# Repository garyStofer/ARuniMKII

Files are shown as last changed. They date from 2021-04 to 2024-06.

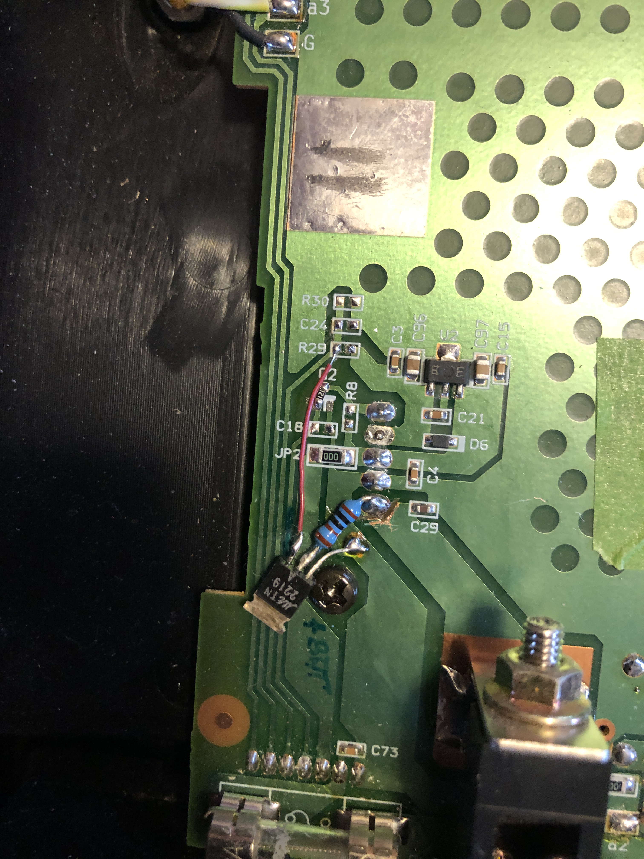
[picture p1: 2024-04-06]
Pictures/IMG_1580.JPG

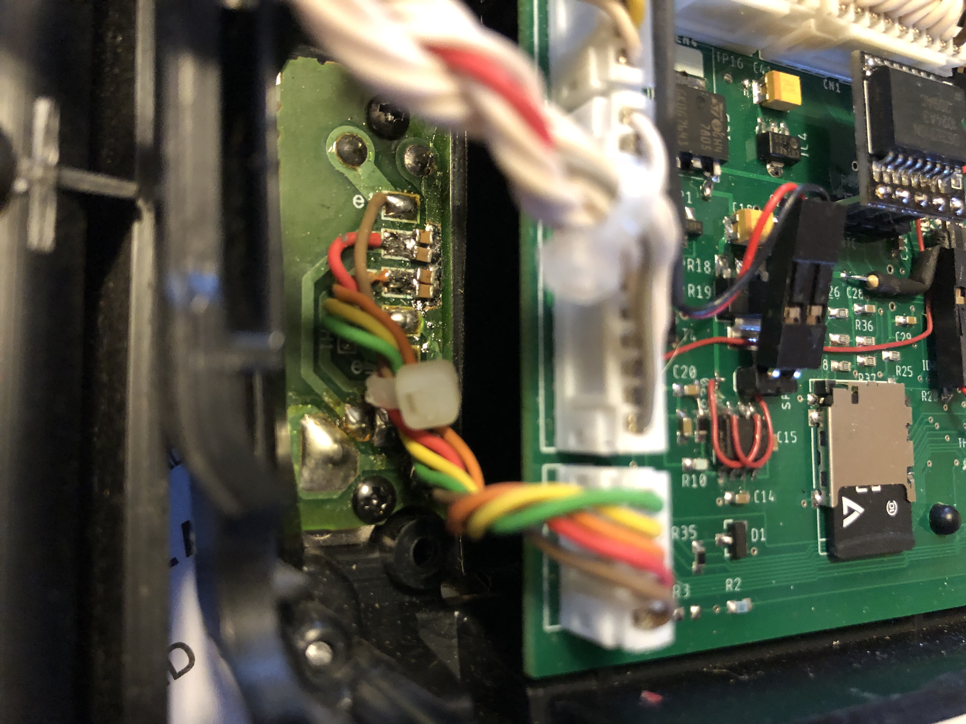
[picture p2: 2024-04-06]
Pictures/IMG_1579.JPG

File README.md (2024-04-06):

# ARuniMKII
PCB  to run ERSKY firmware on old RC transmitters or DIY boxes.

-- Originated from AR9X and ARUni schematic as designed by "flygear" -- on RCgroups

See thread AR9X and ARUni on RC-Groups

Firmware discussions at openrcforums.com under erskyTx (was ersky9x)

Firmware can be found at er9x.com  maintained by Mike Blandford. Use ERSKYTX version  "9XR-PRO" 
Also Pre-Release FW at OpenRCforums : ErskyTX Test Versions by Mike Blandford.

The board is built with an AT-SAM-4 chip with twice the RAM of the original ARUni/AR9x board. See BOM file .
 
The correct chip ID has to be chosen when initially flashing the FW and bootloader to a blank chip with the SAMba tool from Atmel.

firmware src for jr9303 based implementation is at github.com/garyStofer/mbtx

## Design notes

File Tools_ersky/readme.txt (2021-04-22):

These are the latest tools and FW for this board as of  4-2021 -- see er9x.com for more recent versions

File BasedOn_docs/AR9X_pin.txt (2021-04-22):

Corrected AR9X/ARUNI Connector Pin Labels
-----------------------------------------

                             ARUNI Schematic
           AR9X Schematic   (Rev C pin Labels)    MPU Pin     ADC Ch. No.
Sticks
  LV           J3-2         J4-2 (P-ELV_STK)      PA22/AD9         1
  LH           J3-3         J4-3 (P-RUD_STK)      PA19/AD2         0
  RV           J6-2         J6-2 (H-THR_STK)      PC30/AD14        2
  RH           J6-3         J6-3 (H-AIL_STK)      PA18/AD1         3

Pots
  P1           J2-10        J18-2 (F-PO_1)        PA20/AD3         4
  P2           J2-8         J18-4 (F-PO_3)        PC29/AD13        5
  P3           J8-2         J18-3 (F-PO_2)        PB1/AD5          6

Trims
  LVT-U        J3-7         J4-5 (P-ELV_T_DN)     PC28
  LVT-D        J3-9         J4-4 (P-ELV_T_UP)     PA24
  LHT-L        J3-5         J4-7 (P-RUD_T_L)      PA23
  LHT-R        J3-6         J4-6 (P-RUD_T_R)      PB4
  RVT-U        J6-7         J6-5 (H-THR_T_DN)     PA1
  RVT-D        J6-9         J6-4 (H-THR_T_UP)     PC10
  RHT-L        J6-6         J6-7 (H-AIL_T_L)      PA0
  RHT-R        J6-5         J6-6 (H-AIL_T_R)      PC9

NOTE: ARUNI Rev C pin label diagram's:
    - Pots PO_2 and PO_3 got swapped
    - Vertical(ELV/THR) trims' UP/DN got swapped
    - C-RFPWR and C-Board labels got swapped.

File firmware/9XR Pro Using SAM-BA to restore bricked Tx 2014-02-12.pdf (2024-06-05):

DRAFT | 2014-02-12
Using SAM-BA to Restore a “Bricked” Transmitter – version 1 | 1

### 9XR Pro: Using SAM-BA to Restore a “Bricked” Transmitter

The Ersky9x open source firmware used by the Turnigy 9XR Pro computer includes an easy means of communicating between the transmitter and a computer, either via a USB cable or by copying files to a micro-SD card and inserting it into the transmitter.

This capability supports upgrading (flashing) the operating system (firmware) of the transmitter, using a boot loader that comes as part of the firmware. It can also be used to link the transmitter to the Eepskye program, which among other things, enables programming to be performed on the computer and EEPROM files to be backed up to the computer.

What the firmware cannot do is to reload itself if the transmitter becomes “bricked”, i.e., totally unresponsive. In that case, the firmware must be erased from the transmitter and reinstalled. Re-installing requires the use of SAM-BA, a program provided by Atmel, the maker of the ARM microprocessor used by the 9XR Pro transmitter.

### Requirements

As detailed below, SAM-BA is available for download from the Atmel Corporation.

SAM-BA can run under Windows XP, 7 or 8. There is no Macintosh version but it may be possible to run SAM-BA in a Boot Camp Windows partition.

To connect the transmitter to the computer, a USB cable with a Mini-B connector (as used by many older mobile phones) is required. The USB port is under a rubber flap on the bottom of the transmitter. Press the mini USB plug firmly into the socket to ensure that it connects.

Note that some mini-USB cables only support charging. If you encounter a problem connecting, try another cable. Also try a different USB port on the computer. Note that USB 3 ports may not work with any but the newest versions of SAM-BA.

### Installing SAM-BA

- Go to the Atmel Corporation site and download the SAM-BA Version 2.12 file. You will have to register temporarily with Atmel to do so.
- Unzip the file onto your desktop (i.e., right click on the .zip file and select ‘expand file’).
- Open the sam-ba_2.12 file to open the wizard; follow the prompts. The wizard will ask if you wish to install the files in a folder called “Atmel” in the Program Files directory of your hard disk. Answer ‘Yes’ and continue with the prompts.
- The usual path is something like C:\ProgramFiles\Atmel\sam-ba_2.12. Write down or remember where to find this folder. Install a shortcut on the desktop when asked to do so by the wizard. Continue until the wizard is finished.
- Download the file at91sam3s8-9xr.zip from the following location: ‪http://openrcforums.com/forum/viewtopic.php?f=118&t=4553&start=60#p65474
- Unzip the file to a convenient location such as the desktop. It contains a folder called at91sam3s8-9xr.tcl (within which are three applet files and a couple of .tcl files) plus a file called boards.tcl.
- Within the folder where SAM-BA is installed is a folder called tcl_lib. Drag the folder you have just extracted into it. Answer ‘Yes’ to any request to overwrite existing files. The result should be that within the tcl_lib folder (1) the boards.tcl file is replaced (the date may be older than the one it replaces), (2) a new folder called at91sam3s4-9x is created, (3) a new folder called common is created.

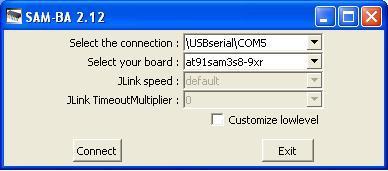
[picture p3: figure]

Using SAM-BA to Restore a “Bricked” Transmitter – version 1 | 2

To check the installation, connect the transmitter (turned OFF) to a USB port on your computer. When you turn the radio on you‪should‪see‪‘USB’‪on‪the‪screen.‪Start the SAM-BA program from the shortcut on the desktop and you will see a dialogue box. From the ‘Select your board’ menu choose at91sam3s8-9xr. If the result looks like the following image (except‪possibly‪for‪a‪different‪COM‪number)‪and‪the‪‘Connect’‪button‪is‪not‪greyed‪ out, you have been successful.

Write down the connection path accurately (including all capitalization) for later reference.

(Note that if you are using Windows XP and the dialogue box shows blanks for connection and‪board,‪you‪may‪need‪to‪find‪and‪install‪a‪driver‪for‪“GPS‪Camera‪Detect.”)

You can now quit SAM-BA.‪Use‪the‪Windows‪‘Safely Remove‪Hardware‪and‪Eject‪Media’ function, then turn off and disconnect the transmitter.

Note that the number following COM is that of the USB port into which you plugged your cable. Try to use this same port whenever you connect to your transmitter. If you do use another port, or forget the number of the one you used, press the Start button (Windows 7) and go to Devices‪and‪Printers.‪There‪under‪‘Unspecified’‪you‪should‪see‪something‪like‪ ‘GPS Camera Detect (COM5)’. Edit the COM number in the SAM-BA connection to match.

### Using SAM-BA to Recover a Bricked Transmitter

A transmitter‪that‪is‪unresponsive‪(‘bricked’) because of a firmware issue requires that the ARM processor chip be restored to factory defaults and that fresh firmware be flashed to it using the SAM-BA program.

New releases of firmware are available at: http://ersky9x.googlecode.com/svn/trunk/ersky9x_rom.bin

Step 1: Erasing the Chip
- While turning ON the transmitter, use a paperclip to press and hold the small round Erase Button. It is in a hole beside the USB connector, under the rubber flap on the bottom of the transmitter. The Atmel ARM chip will be reset to factory defaults.

Caution: Pressing the Erase Button completely wipes the firmware off the chip; it does NOT restore the transmitter to original firmware.

Step 2: Updating Firmware
- Download the firmware file to the desktop or a folder where you can find it later. Unzip the file if necessary. The firmware will be in a file such as ersky9xr_rom.bin.
- Connect the transmitter to the same USB port on your computer that was used to install SAM-BA. Turn the transmitter ON. The radio should display ‘USB’ on the screen and the computer make the ‘successful connection’ sound.
- Start SAM-BA from the shortcut on the desktop. You will see the SAM-BA dialogue box.

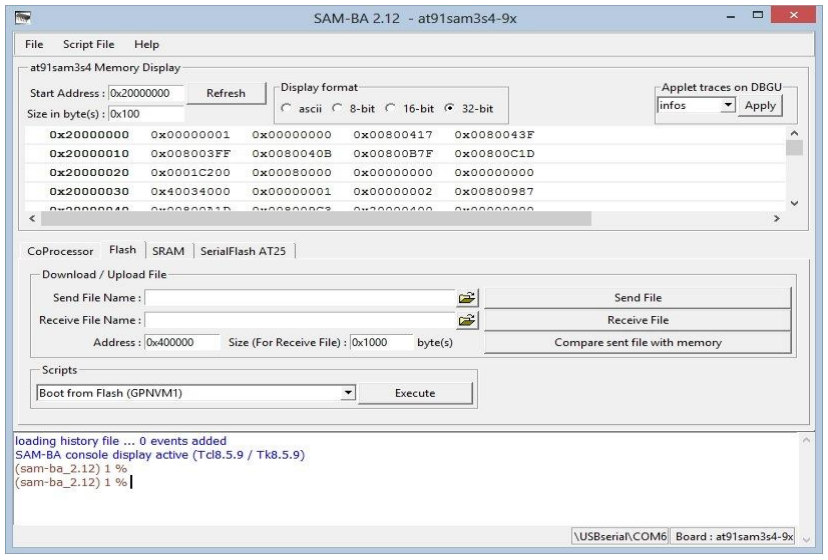
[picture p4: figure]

Using SAM-BA to Restore a “Bricked” Transmitter – version 1 | 3
- Click ‘Connect’. Windows may take up to a minute to connect. You should see:
- Use the browse button next to the "Send File Name" Box to locate and select the new firmware file on your computer.
- Click the "Send File" button. You should see the file upload in the dialog box at the bottom – the process should only take a couple of seconds to complete. The new firmware is now installed (including the boot loader for future firmware updates).
- In‪Scripts‪window‪near‪the‪bottom‪of‪the‪page‪select‪“Boot‪from‪Flash‪(GPNVM1)”
- Click the Execute button.
- After the programming is finished, you will see an option to ‘lock’ the firmware. DO NOT LOCK THE FIRMWARE! Select the "No" button. (If you do accidentally press "Yes" and lock the firmware, it will be necessary to erase the chip and reload the firmware. Otherwise it will be impossible to do any updates.)
- Quit SAM-BA. Then use ‘Safely‪Remove‪Hardware‪and‪Eject‪Media’,‪turn the transmitter OFF and disconnect the USB cable.
- Turn on the transmitter and check its operation with the new firmware.

### NOTES

- SAM-BA only works once each time it is started. After each use you must quit SAM-BA, turn off the radio, and disconnect the transmitter from the USB port. Only then can you reconnect and upload or download a file.
- It is important to connect the transmitter to your computer and turn it on before starting SAM-BA, otherwise the program will not work.
- Be sure to quit the SAM-BA program before shutting down the transmitter.
- To enter boot loader mode, turn on the transmitter while holding the two horizontal trim levers towards the centre; the transmitter is then ready to flash firmware. As well, in this mode, the USB cable can be used to connect with the computer. For details, see
9XR Pro: Communicating with a Computer.

Using SAM-BA to Restore a “Bricked” Transmitter – version 1 | 4

### Further Information

For additional information to help you understand and make best use of your Turnigy 9XR Pro, see the other manuals in this series and/or go to one of the forums dedicated to this transmitter and the open source firmware it uses.

9XR Pro Manuals
The following manuals are designed to help you get the most out of your Turnigy 9XR Pro. They are available at: http://openrcforums.com/forum/viewforum.php?f=7
1. 9XR Pro: Introduction to the Hardware
2. 9XR Pro: First Steps with Ersky9x
3. 9XR Pro: Ersky9x Explained
4. 9XR Pro: Communicating with a Computer
5. 9XR Pro: Using Voice with Ersky9x
6. 9XR Pro: Using the Eepskye Program
7. 9XR Pro: Glossary of Terms

Internet Forums
Help is always just a few clicks away on the internet forums where experienced Ersky9x users volunteer their knowledge and experience. Many of these people have been developing the firmware for years without remuneration; all they ask is donations to fund further development.

Open RC Forums: http://openrcforums.com/forum/index.php

Ersky9x index page: http://openrcforums.com/forum/

9XR index page: http://openrcforums.com/forum/viewforum.php?f=70

### NOTICE

Ersky9x and Eepskye are free open source software, independently developed. This manual is provided to help you understand and use them specifically for the Turnigy 9XR Pro transmitter, though much of the information also applies to the Sky replacement boards produced as an upgrade for the 9x transmitter.

You can redistribute the software and/or modify it under the terms of the GNU General Public License version 2 as published by the Free Software Foundation. You can also freely quote from, redistribute and/or modify this manual; in doing so please acknowledge the source and any changes.

The program and the manuals are distributed in the hope that they will be useful, but WITHOUT ANY WARRANTY; without even the implied warranty of MERCHANTABILITY or FITNESS FOR A PARTICULAR PURPOSE. See the GNU General Public License for more details. In using them, you agree that you accept all responsibility.

For more information go to: http://openrcforums.com/forum/viewforum.php?f=7

9XR Pro Using SAM-BA to restore bricked Tx 2014-02-12

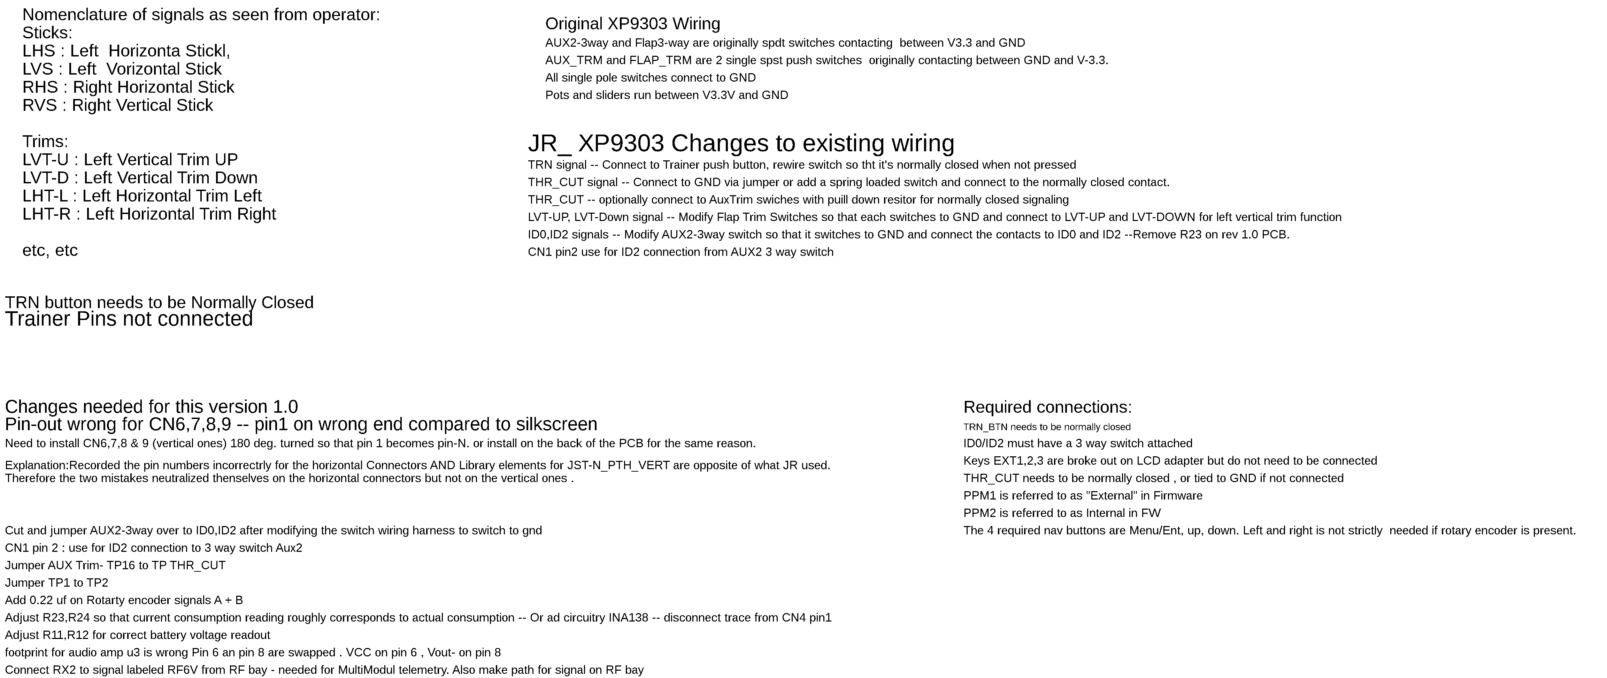
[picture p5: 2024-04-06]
Pictures/page2.png

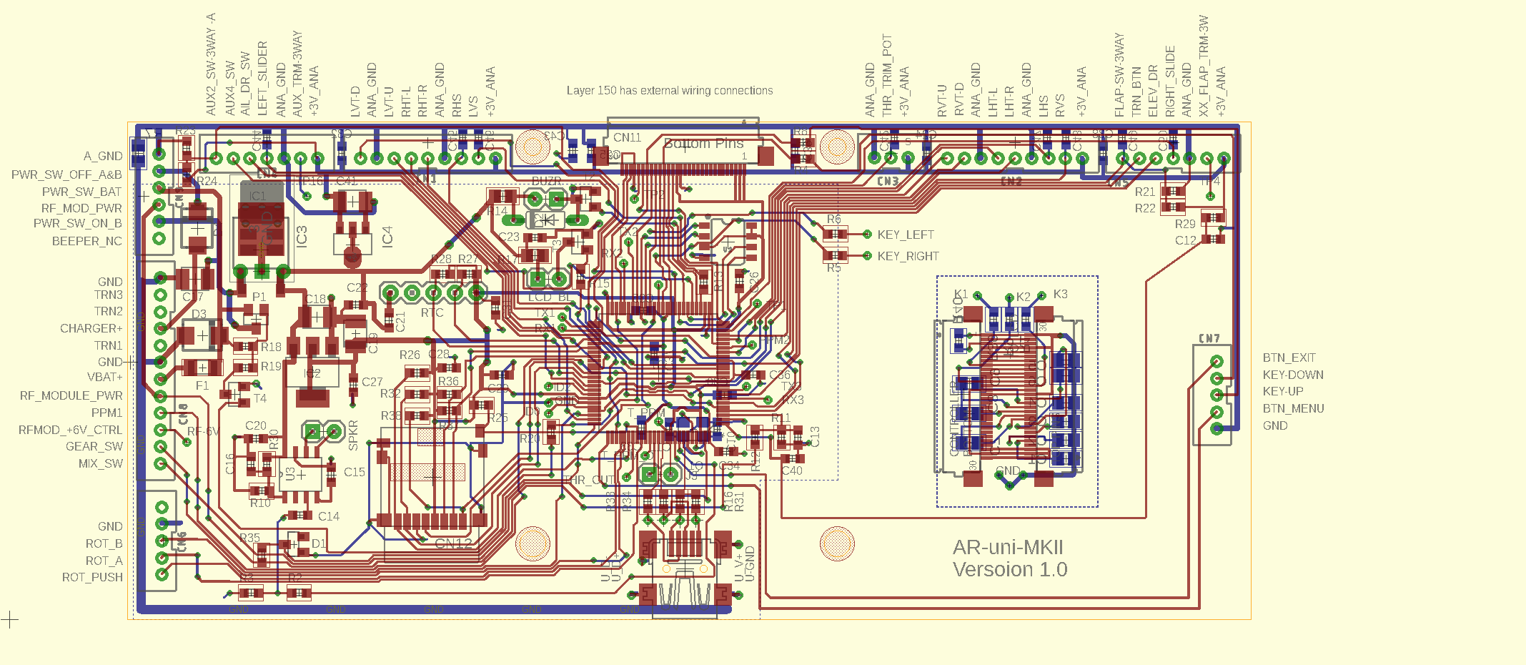
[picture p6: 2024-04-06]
Pictures/pcb_front .png

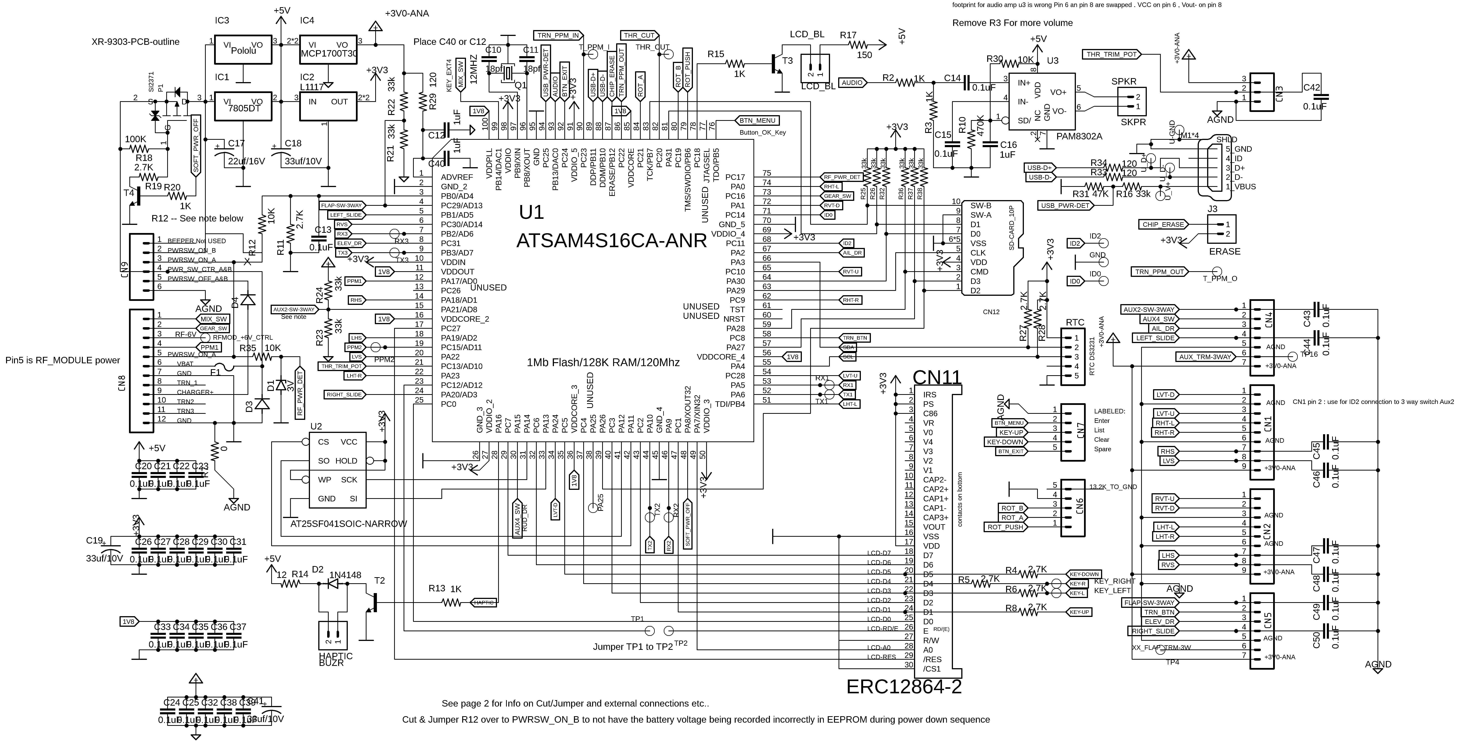
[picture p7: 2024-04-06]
Pictures/page1.png

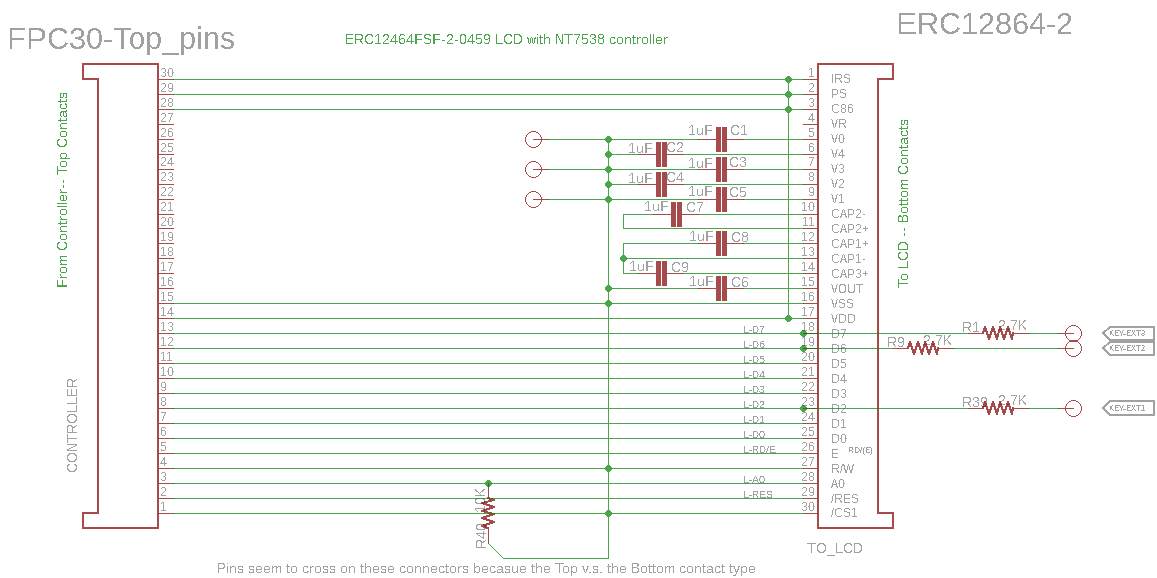
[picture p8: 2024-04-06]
Pictures/Page3_sch.png

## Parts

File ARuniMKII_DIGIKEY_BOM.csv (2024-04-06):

Manufacturer Part Number | Manufacturer | Digi-Key Part Number | Customer Reference | Reference Designator | Packaging | Part Status | Quantity | Unit Price | Extended Price | Quantity Available | Mfg Std Lead Time | Description | RoHS Status | Lead Free Status | REACH Status
ATSAM4S16CA-ANR | Microchip Technology | 1611-ATSAM4S16CA-ANRCT-ND |  |  | Cut Tape (CT) | Active | 2 | 3.03000 | $6.06 | 391 | 27 Weeks | IC MCU 32BIT 1MB FLASH 100LQFP | ROHS3 Compliant | Lead free | REACH Unaffected
DM3D-SF | Hirose Electric Co Ltd | HR1941CT-ND |  |  | Cut Tape (CT) | Active | 2 | 1.65000 | $3.30 | 0 | 12 Weeks | CONN MICRO SD CARD PUSH-PULL | RoHS Compliant | Lead free | Not Available
SI2371EDS-T1-GE3 | Vishay Siliconix | SI2371EDS-T1-GE3CT-ND |  |  | Cut Tape (CT) | Active | 10 | 0.31600 | $3.16 | 57370 | 19 Weeks | MOSFET P-CH 30V 4.8A SOT-23 | ROHS3 Compliant | Lead free | Not Available
SF-1206SP175L-2-A9 | Bourns Inc. | 118-SF-1206SP175L-2-A9CT-ND |  |  | Cut Tape (CT) | Active | 5 | 0.20200 | $1.01 | 8499 | 20 Weeks | FUSE BOARD MNT 1.75A 63VDC 1206 | ROHS3 Compliant | Lead free | REACH Unaffected
PAM8302AADCR | Diodes Incorporated | PAM8302AADCRDICT-ND |  |  | Cut Tape (CT) | Active | 2 | 0.65000 | $1.30 | 4154 | 36 Weeks | IC AMP CLASS D MONO 2.5W 8SOP | ROHS3 Compliant | Lead free | REACH Unaffected
TPSB336K010R0500 | AVX Corporation | 478-9074-1-ND |  |  | Cut Tape (CT) | Active | 10 | 0.31700 | $3.17 | 505 | 33 Weeks | CAP TANT 33UF 10% 10V 1411 | ROHS3 Compliant | Lead free | REACH Unaffected
TPSB226K016R0600 | AVX Corporation | 478-1758-1-ND |  |  | Cut Tape (CT) | Active | 2 | 0.50000 | $1.00 | 0 | 33 Weeks | CAP TANT 22UF 10% 16V 1411 | ROHS3 Compliant | Lead free | REACH Unaffected
LDL1117S33R | STMicroelectronics | 497-17239-1-ND |  |  | Cut Tape (CT) | Active | 2 | 0.38000 | $0.76 | 0 | 26 Weeks | IC REG LINEAR 3.3V 1.2A SOT223 | ROHS3 Compliant | Not Available | REACH Unaffected
BZX84B3V0-7-F | Diodes Incorporated | BZX84B3V0-FDICT-ND |  |  | Cut Tape (CT) | Active | 2 | 0.20000 | $0.40 | 19778 | 34 Weeks | DIODE ZENER 3V 300MW SOT23 | ROHS3 Compliant | Lead free | REACH Unaffected
MCP1700T-3002E/MB | Microchip Technology | MCP1700T-3002E/MBCT-ND |  |  | Cut Tape (CT) | Active | 2 | 0.39000 | $0.78 | 0 | 10 Weeks | IC REG LINEAR 3V 250MA SOT89-3 | ROHS3 Compliant | Lead free | REACH Unaffected
SFV30R-2STBE1HLF | Amphenol ICC (FCI) | 609-5394-1-ND |  |  | Cut Tape (CT) | Active | 1 | 0.64000 | $0.64 | 10225 | 14 Weeks | CONN FFC TOP 30POS 0.50MM R/A | RoHS Compliant | Lead free | REACH Unaffected
0151660319 | Molex | 0151660319-ND |  |  | Bag | Active | 2 | 1.97000 | $3.94 | 438 | 10 Weeks | CABLE FFC 30POS 0.50MM 3" | ROHS3 Compliant | Lead free | Not Available
68713014522 | Würth Elektronik | 732-3518-1-ND |  |  | Cut Tape (CT) | Active | 4 | 1.62000 | $6.48 | 2728 | 11 Weeks | CONN FPC BOTTOM 30POS 0.50MM R/A | ROHS3 Compliant | Lead free | REACH Unaffected
68713014022 | Würth Elektronik | 732-3517-1-ND | top pins |  | Cut Tape (CT) | Active | 2 | 1.67000 | $3.34 | 1897 | 11 Weeks | CONN FPC TOP 30POS 0.50MM R/A | ROHS3 Compliant | Lead free | REACH Unaffected
RMCF0603FT2K70 | Stackpole Electronics Inc | RMCF0603FT2K70CT-ND |  |  | Cut Tape (CT) | Active | 100 | 0.00680 | $0.68 | 0 | 21 Weeks | RES 2.7K OHM 1% 1/10W 0603 | ROHS3 Compliant | Lead free | REACH Unaffected
WR06X3302FTL | Walsin Technology Corporation | 1292-WR06X3302FTLCT-ND |  |  | Cut Tape (CT) | Active | 100 | 0.00560 | $0.56 | 4302 | 25 Weeks | RES 33K OHM 1% 1/10W 0603 | ROHS3 Compliant | Not Available | REACH Unaffected
CR0603-JW-104ELF | Bourns Inc. | CR0603-JW-104ELFCT-ND |  |  | Cut Tape (CT) | Active | 100 | 0.00530 | $0.53 | 50214 | 14 Weeks | RES SMD 100K OHM 5% 1/10W 0603 | ROHS3 Compliant | Lead free | REACH Unaffected
690-005-299-043 | EDAC Inc. | 151-1206-1-ND |  |  | Cut Tape (CT) | Active | 2 | 0.54000 | $1.08 | 71096 | 17 Weeks | CONN RCPT USB2.0 MINI B SMD R/A | ROHS3 Compliant | Lead free | REACH Unaffected
B12B-PH-K-S(LF)(SN) | JST Sales America Inc. | 455-1714-ND |  |  | Bulk | Active | 2 | 0.53000 | $1.06 | 3158 | 24 Weeks | CONN HEADER VERT 12POS 2MM | ROHS3 Compliant | Lead free | Not Available
B7B-PH-K-S(LF)(SN) | JST Sales America Inc. | 455-1709-ND |  |  | Bulk | Active | 4 | 0.39000 | $1.56 | 359 | 24 Weeks | CONN HEADER VERT 7POS 2MM | ROHS3 Compliant | Lead free | Not Available
B6B-PH-K-S(LF)(SN) | JST Sales America Inc. | 455-1708-ND |  |  | Bulk | Active | 4 | 0.33000 | $1.32 | 11870 | 24 Weeks | CONN HEADER VERT 6POS 2MM | ROHS3 Compliant | Lead free | REACH Unaffected
SWR201-NRTN-S05-SA-WH | Sullins Connector Solutions | S9450-ND |  |  | Bulk | Active | 4 | 0.22000 | $0.88 | 1435 | 4 Weeks | CONN HEADER VERT 5POS 2MM | ROHS3 Compliant | Lead free | REACH Unaffected
SWR201-NRTN-S03-SA-WH | Sullins Connector Solutions | S9456-ND |  |  | Bulk | Active | 2 | 0.17000 | $0.34 | 2064 | 5 Weeks | CONN HEADER VERT 3POS 2MM | ROHS3 Compliant | Lead free | REACH Unaffected
440054-9 | TE Connectivity AMP Connectors | A100041-ND |  |  | Bulk | Active | 4 | 0.59000 | $2.36 | 0 | 25 Weeks | CONN HEADER VERT 9POS 2MM | RoHS Compliant | Lead free | Not Available
LFXTAL083388RL3K | IQD Frequency Products | 1923-LFXTAL083388RL3KCT-ND |  |  | Cut Tape (CT) | Active | 2 | 0.66000 | $1.32 | 2433 | 19 Weeks | CRYSTAL 12.0000MHZ 12PF SMD | ROHS3 Compliant | Not Available | Not Available
CL10C120JB8NNNC | Samsung Electro-Mechanics | 1276-1254-1-ND |  |  | Cut Tape (CT) | Active | 50 | 0.01720 | $0.86 | 136019 | 28 Weeks | CAP CER 12PF 50V C0G/NP0 0603 | ROHS3 Compliant | Lead free | REACH Unaffected
MMBT3904-7-F | Diodes Incorporated | MMBT3904-FDICT-ND |  |  | Cut Tape (CT) | Active | 25 | 0.08280 | $2.07 | 636895 | 20 Weeks | TRANS NPN 40V 0.2A SMD SOT23-3 | ROHS3 Compliant | Lead free | REACH Unaffected
AT25SF041B-SHD-B | Adesto Technologies | 1265-AT25SF041B-SHD-B-ND |  |  | Tube | Active | 2 | 0.36000 | $0.72 | 8168 | 12 Weeks | IC FLASH 4MBIT SPI/QUAD 8SOIC | ROHS3 Compliant | Not Available | REACH Unaffected

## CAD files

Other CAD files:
BasedOn_docs/ARUni_Wiring_v14.dwg

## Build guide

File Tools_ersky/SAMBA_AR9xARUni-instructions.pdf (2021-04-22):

AR9x, ARUni Firmware flashing via SAM-BA tool

*CHIP_ERASE can be done short “CHIP_ERASE” pin to 3.3V and power up the board.

### 1. Ready board as powered off 2. Install SAM-BA program on your PC

(https://www.rcgroups.com/forums/showatt.php?attachmentid=8531632&d=1450682596)

### 3. Connect micro USB cable between PC and the board (Powered off) 4. Power up the board 5. Driver for “Bossa Program Port” is being installed

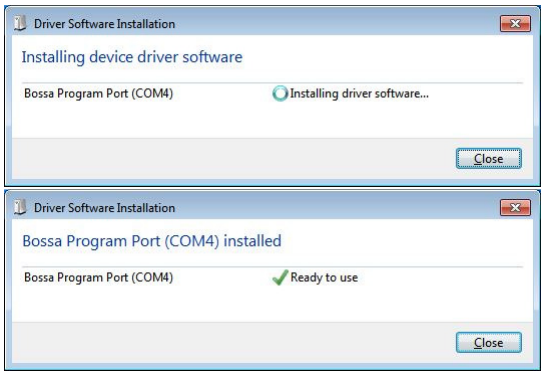
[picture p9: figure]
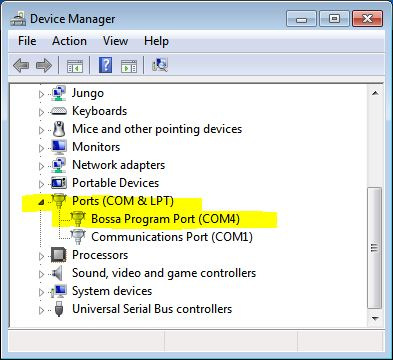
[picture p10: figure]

6. Confirm “Bossa Program Port” is installed on the Windows device manager.

### 7. Excute SAM-BA from PC

### 8. Select the connection & board type and Click “Connect”

a. Check your board type first refer (https://static.rcgroups.net/forums/attachments/3/1/9/8/5/0/a8977372-192-a8828688-168-AR9x_lot_1.PNG)
b. If your board type is “3S8” select your board type as “at91sam3s8-ek”

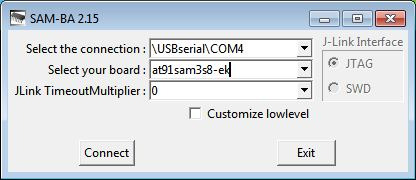
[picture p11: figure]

c. If your board type is “3SD8” select your board type as “at91sam3sd8-ek”

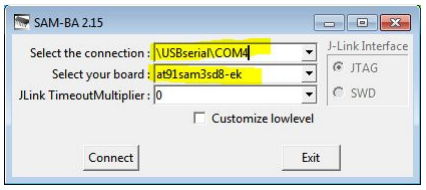
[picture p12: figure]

### 9. Choose the firmware you want to send to the board

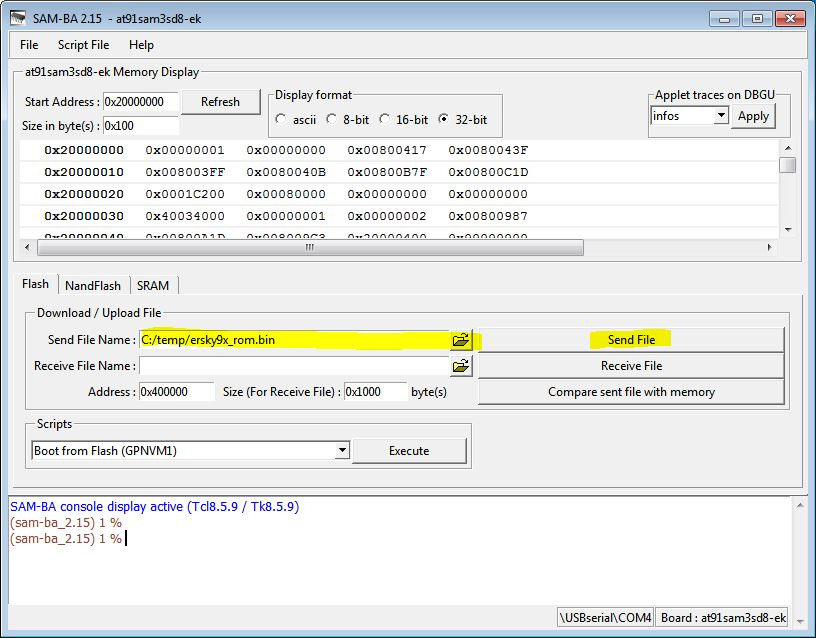
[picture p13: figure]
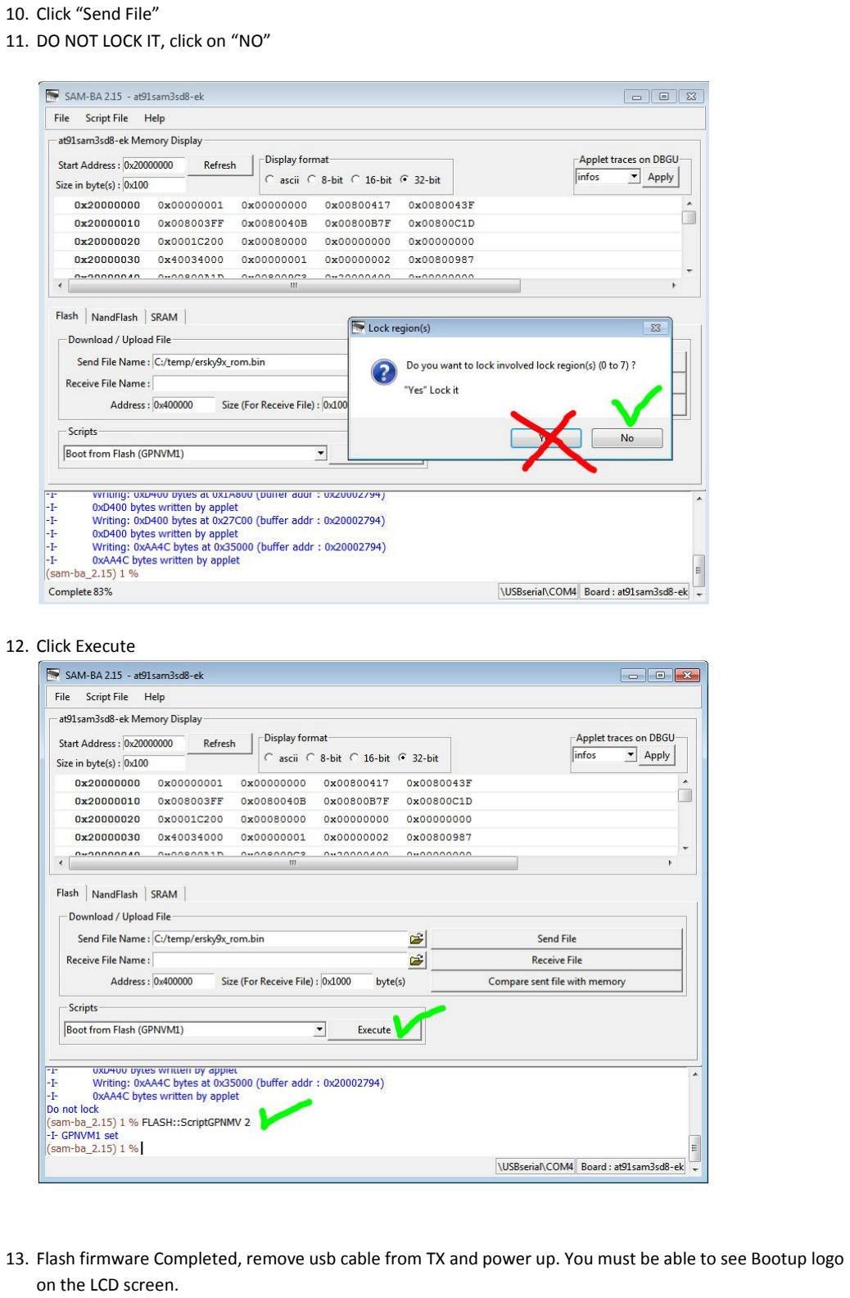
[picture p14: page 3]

### 10. Click “Send File” 11. DO NOT LOCK IT, click on “NO”

### 12. Click Execute

13. Flash firmware Completed, remove usb cable from TX and power up. You must be able to see Bootup logo on the LCD screen.

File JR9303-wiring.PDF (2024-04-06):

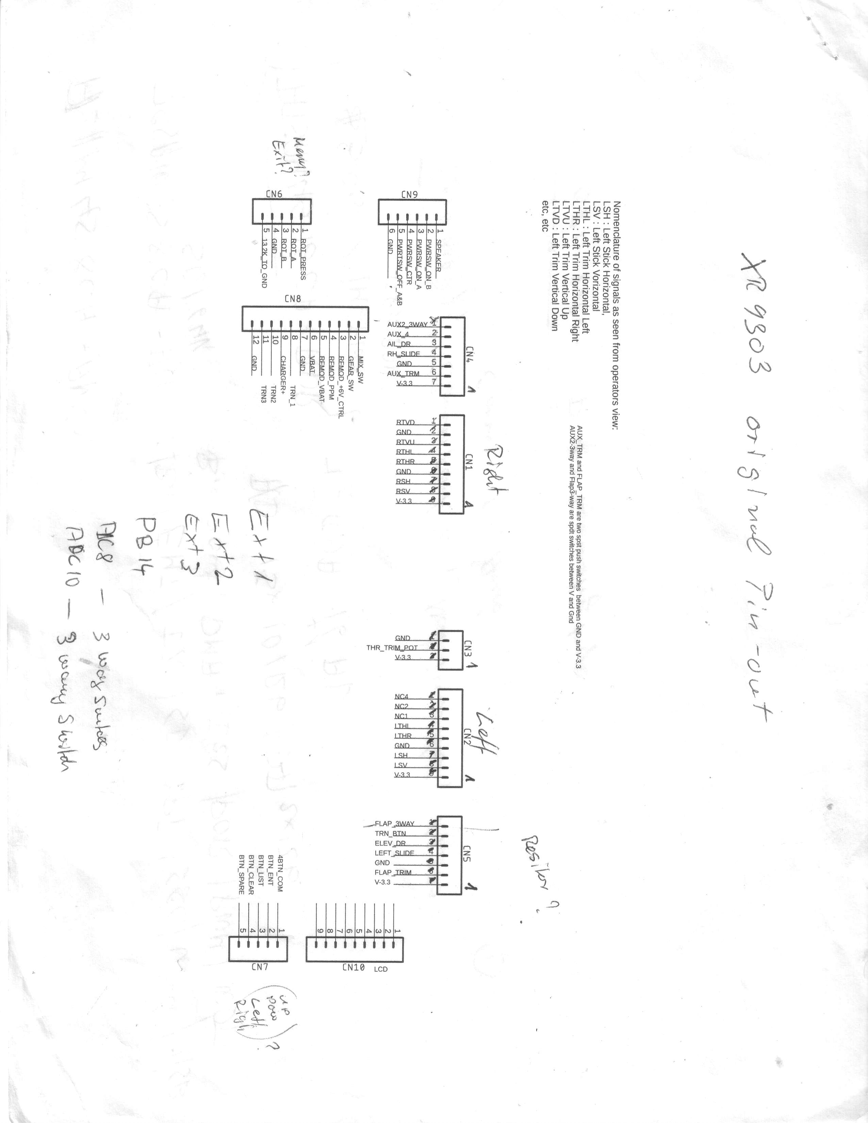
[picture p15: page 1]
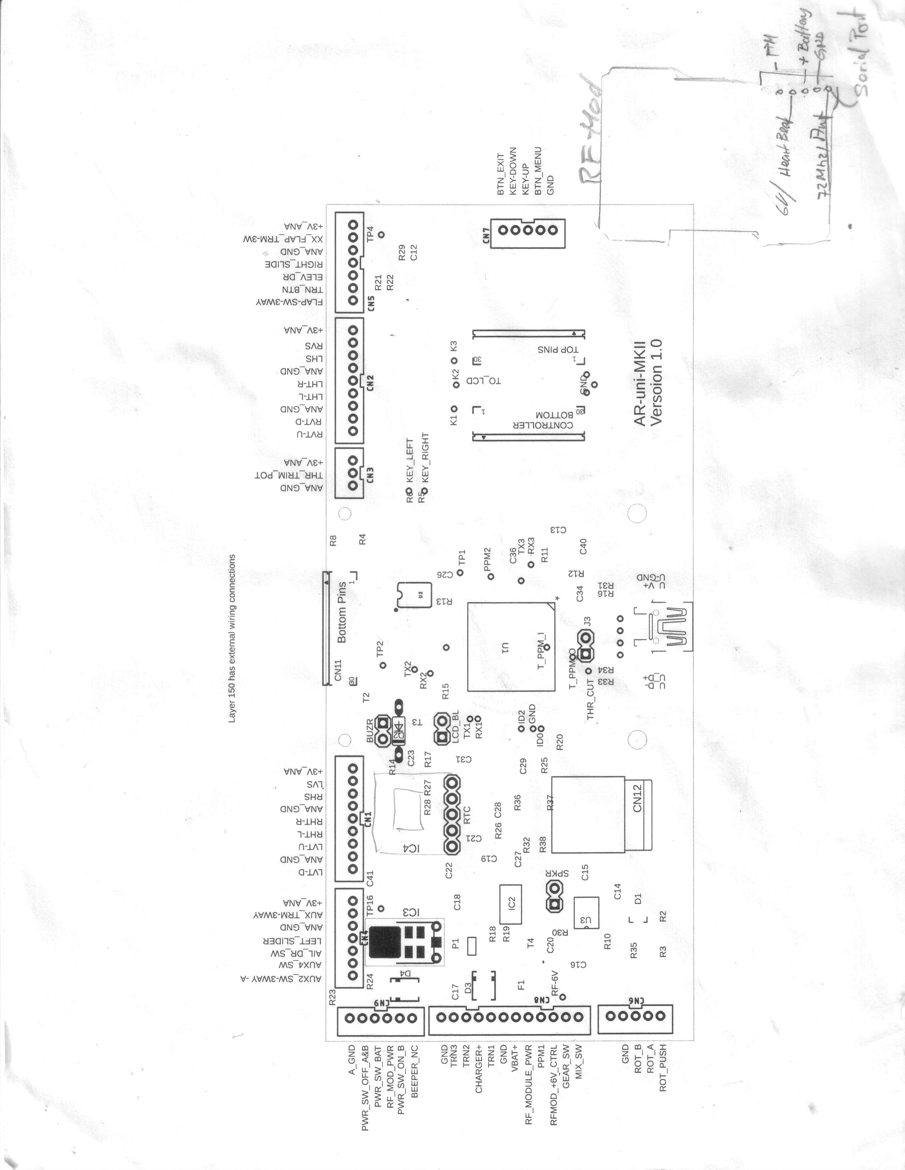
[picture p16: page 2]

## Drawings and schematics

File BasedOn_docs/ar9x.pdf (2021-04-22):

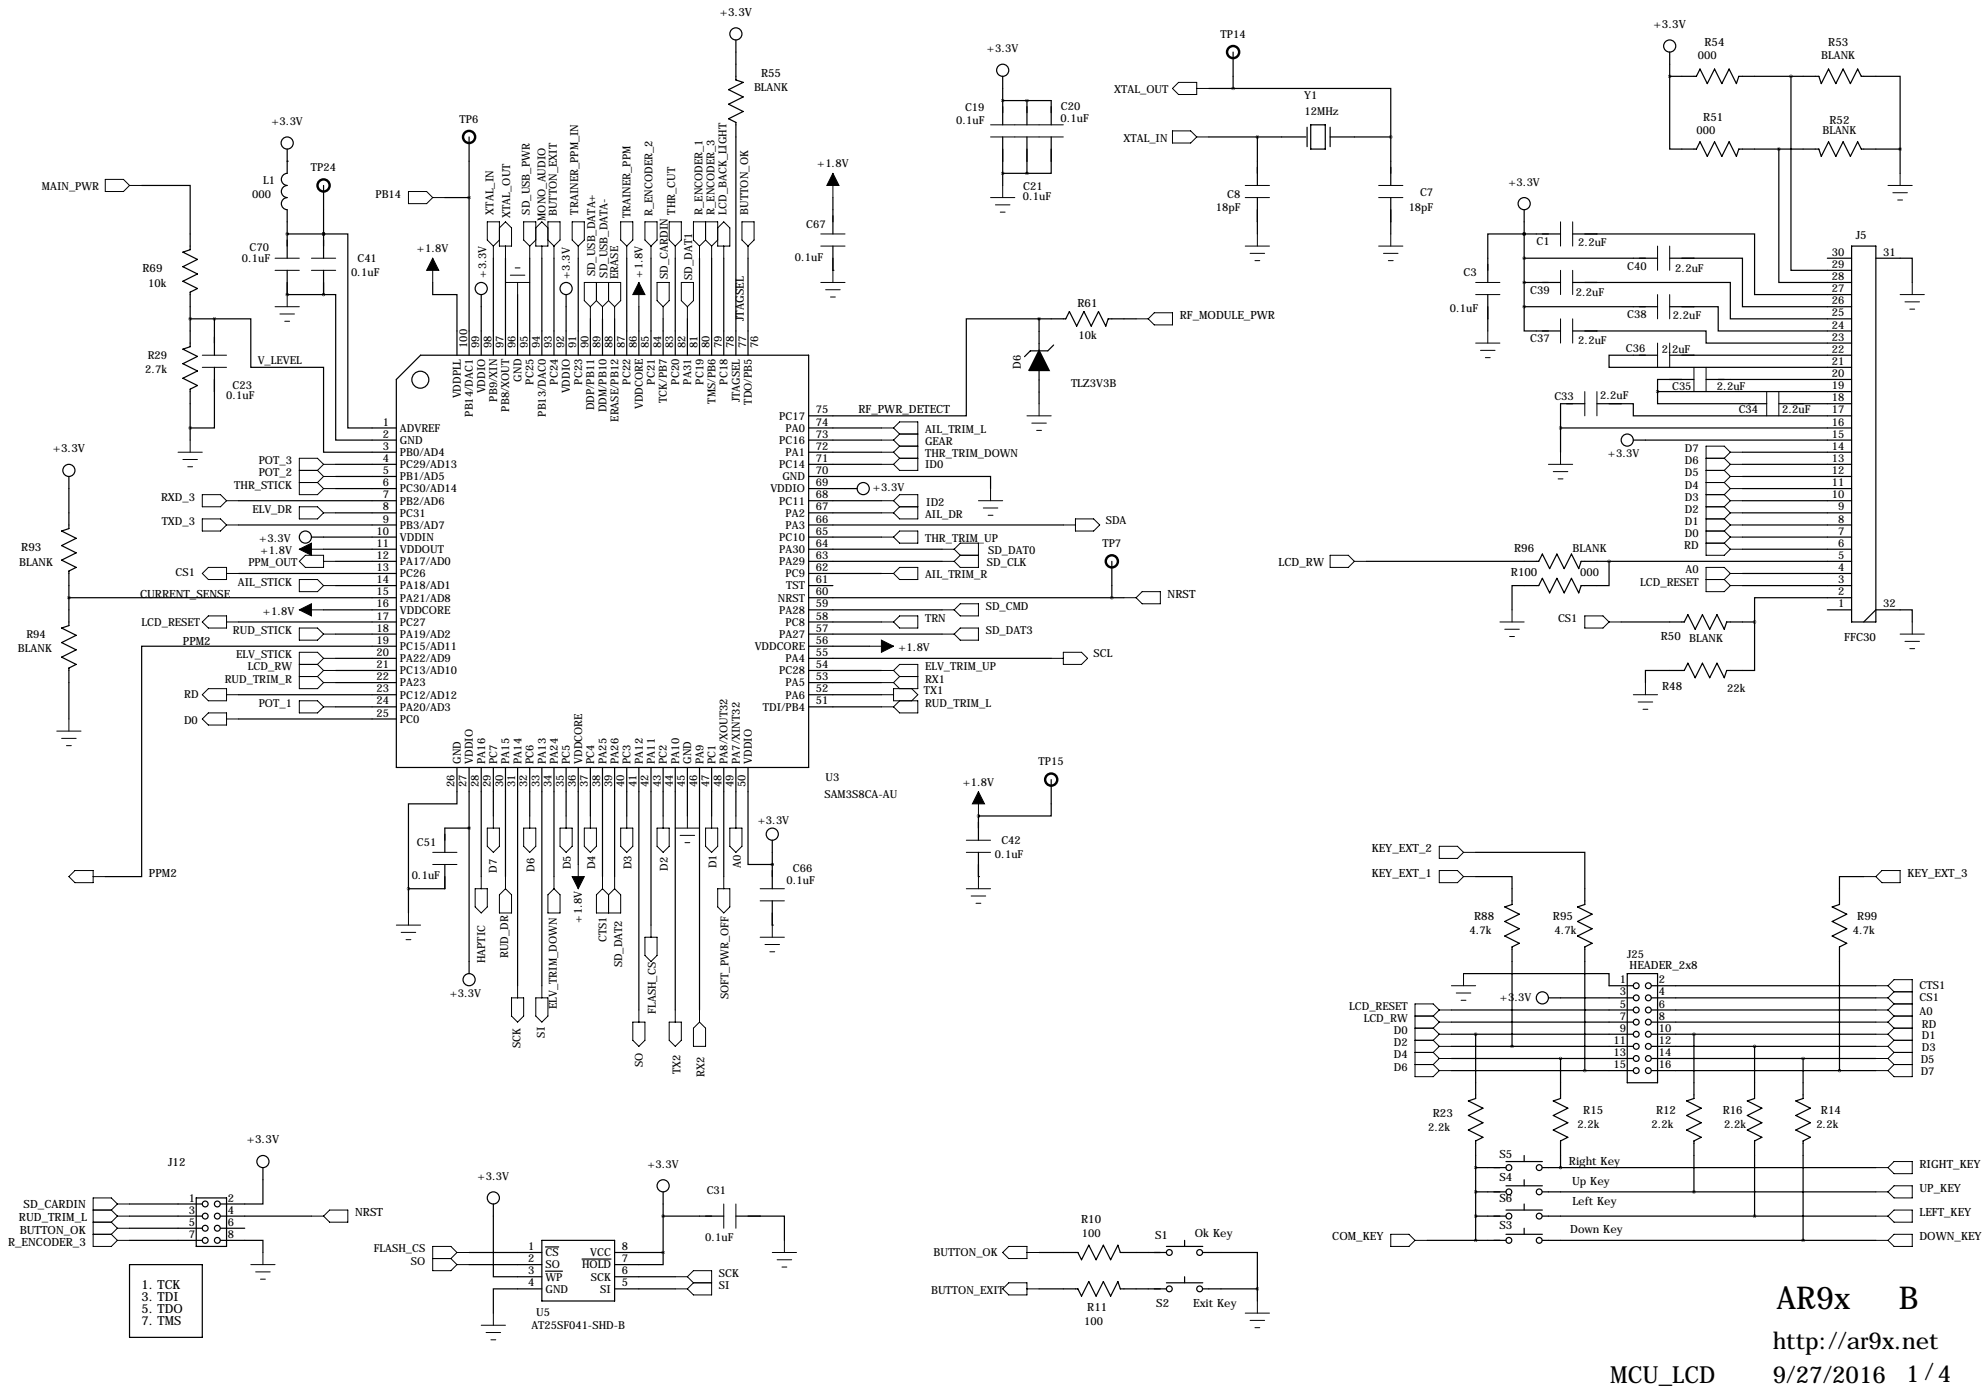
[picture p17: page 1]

76 TDO/PB5 77 JTAGSEL 78 PC18 79 TMS/PB6 80 PC19 81 PA31 82 PC20 83 TCK/PB7 84 PC21 85 VDDCORE 86 PC22 87 ERASE/PB12 88 DDM/PB10 89 DDP/PB11 90 PC23 91 VDDIO 92 PC24 93 PB13/DAC0 94 PC25 95 GND 96 PB8/XOUT 97 PB9/XIN 98 VDDIO 99 PB14/DAC1 100 VDDPLL

# PWR Slide SW

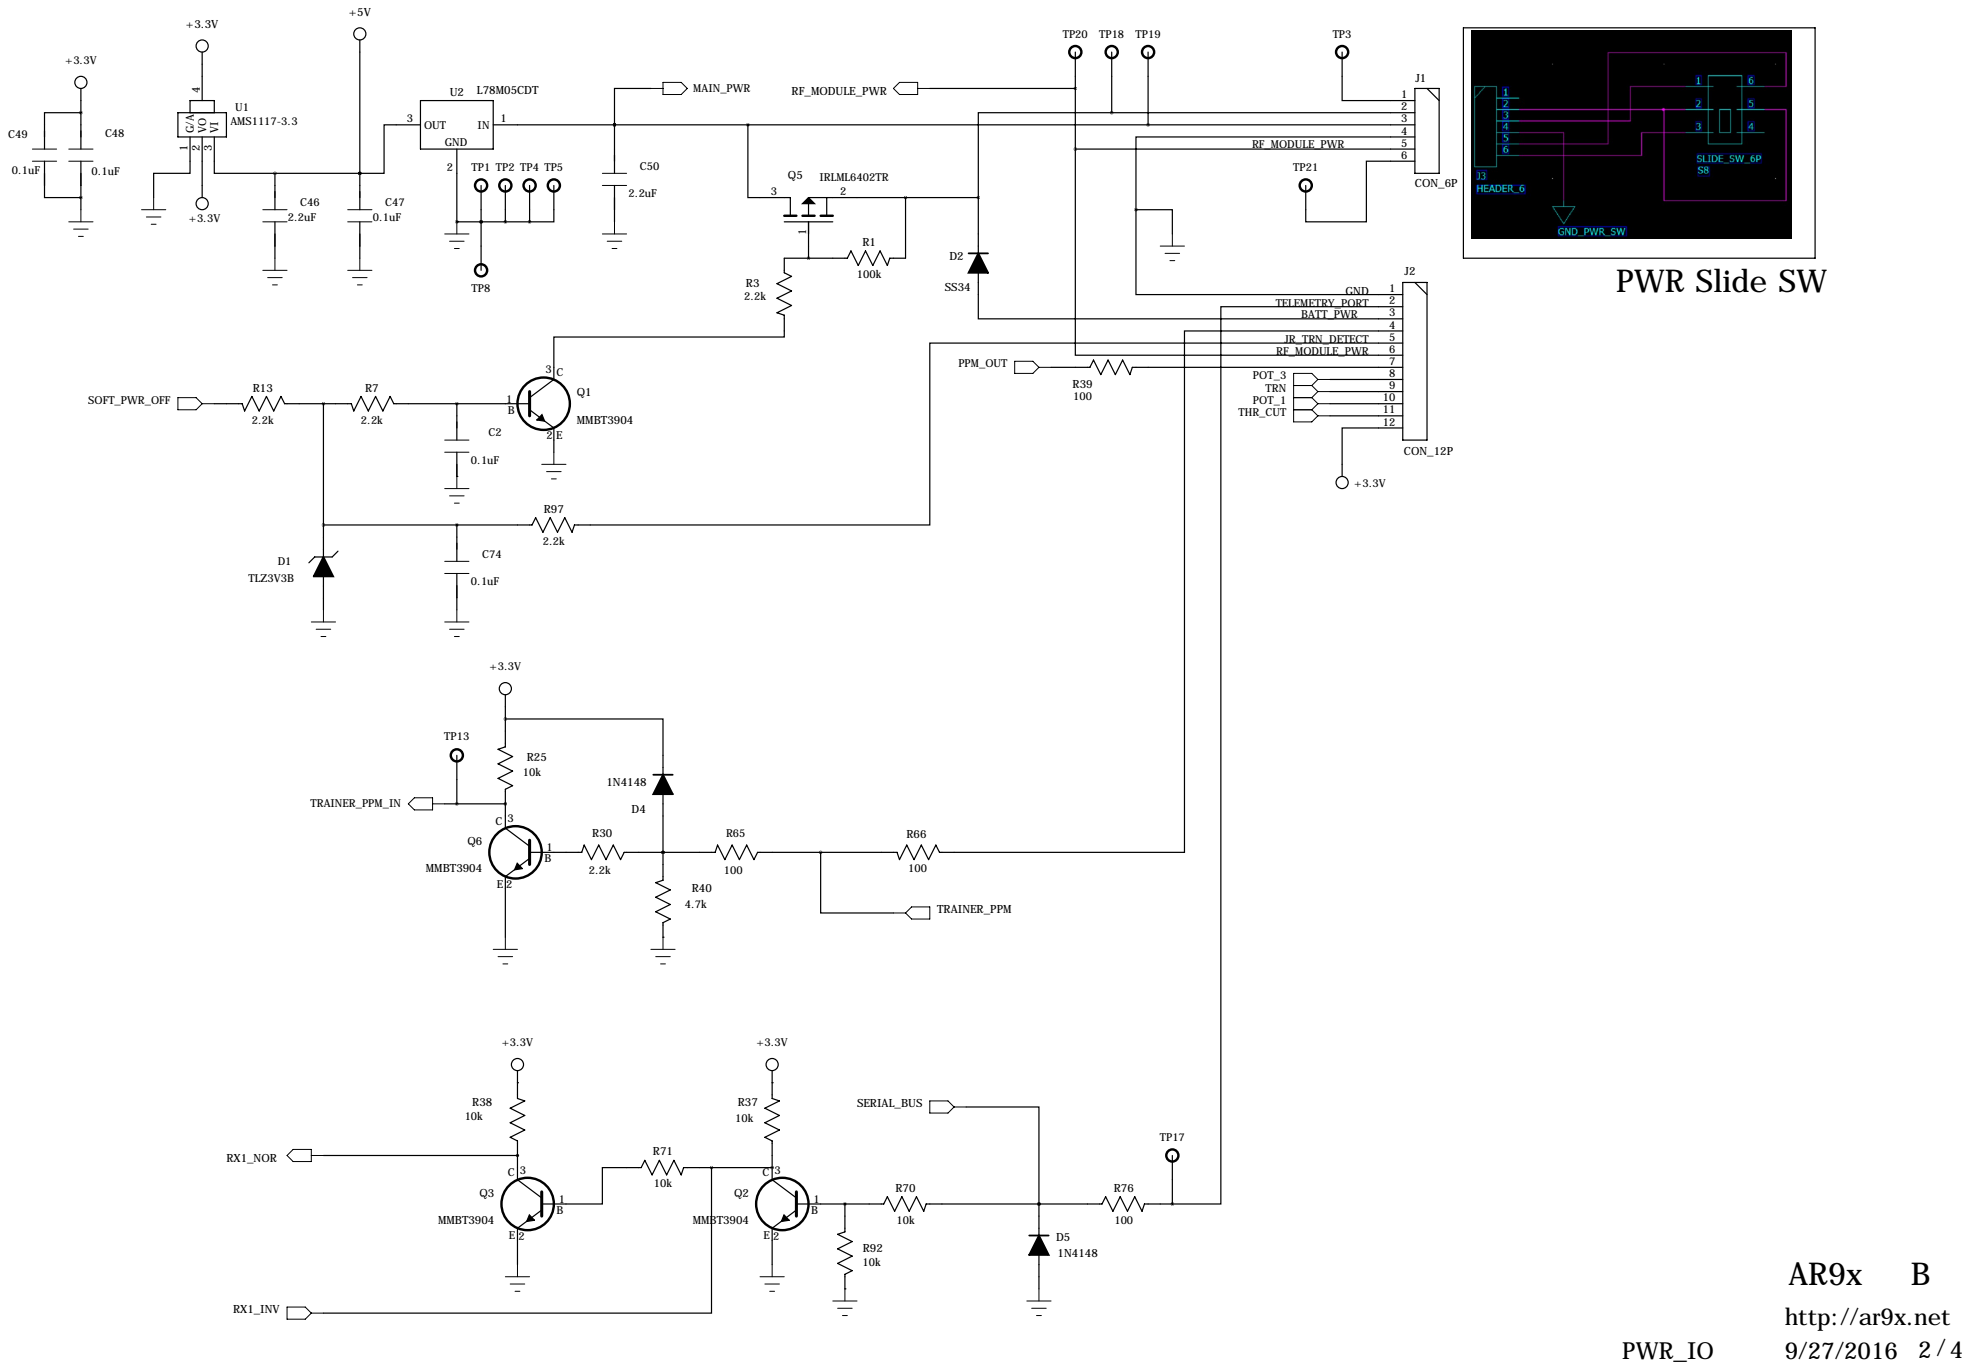
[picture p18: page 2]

JR_TRN_DETECT 5
6 RF_MODULE_PWR

8 9 10 11 12

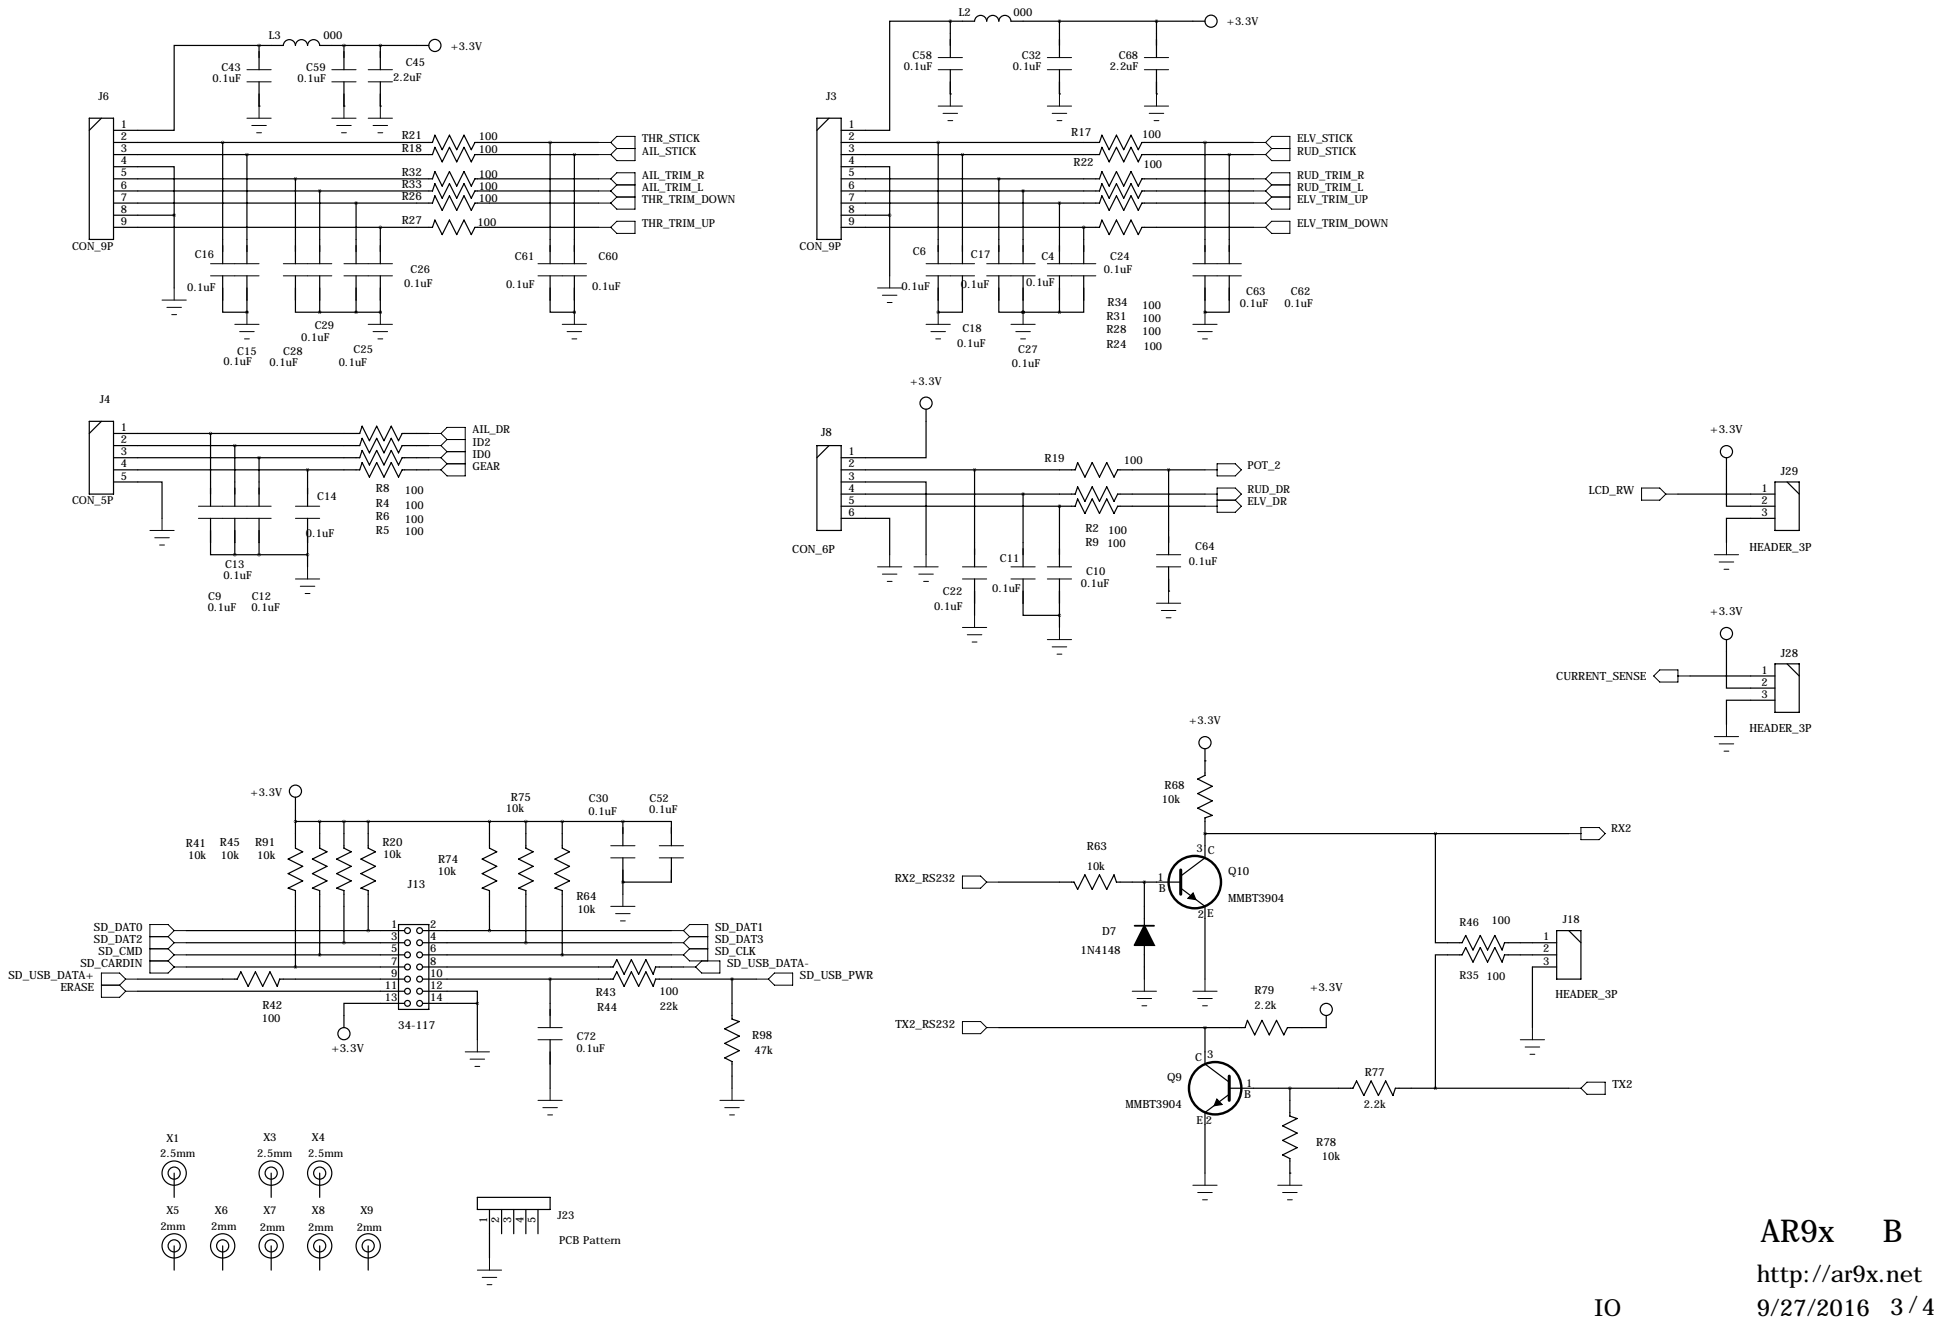
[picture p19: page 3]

# +5V_AUD⁺⁵V_AUD

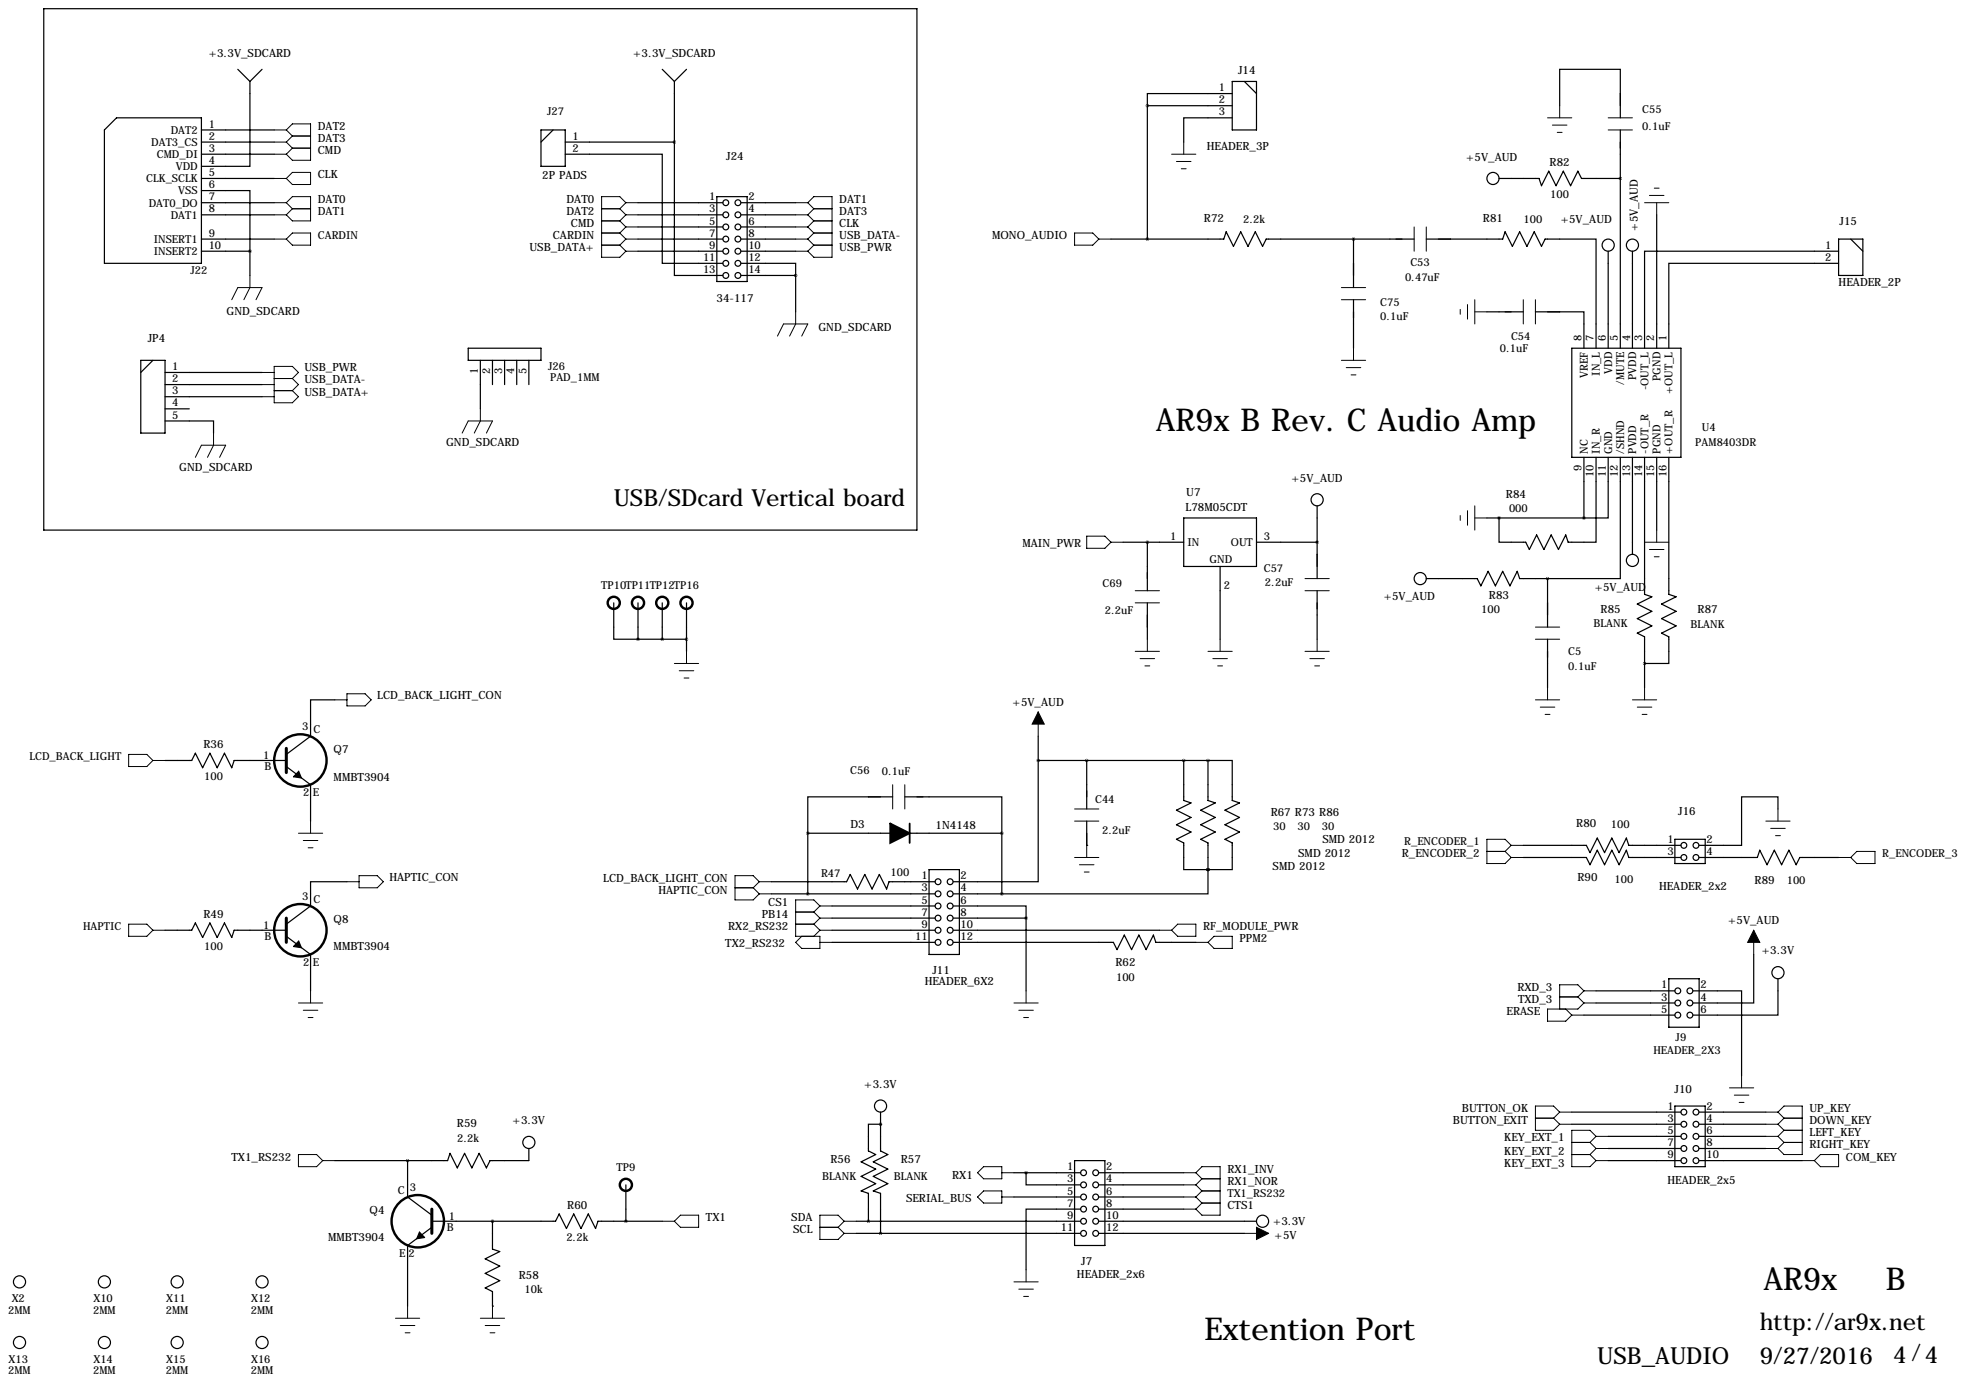
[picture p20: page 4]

9 NC 10 IN_R 11 GND 12 /SHND 13 PVDD 14 -OUT_R 15 PGND 16 +OUT_R

USB/SDcard Vertical board

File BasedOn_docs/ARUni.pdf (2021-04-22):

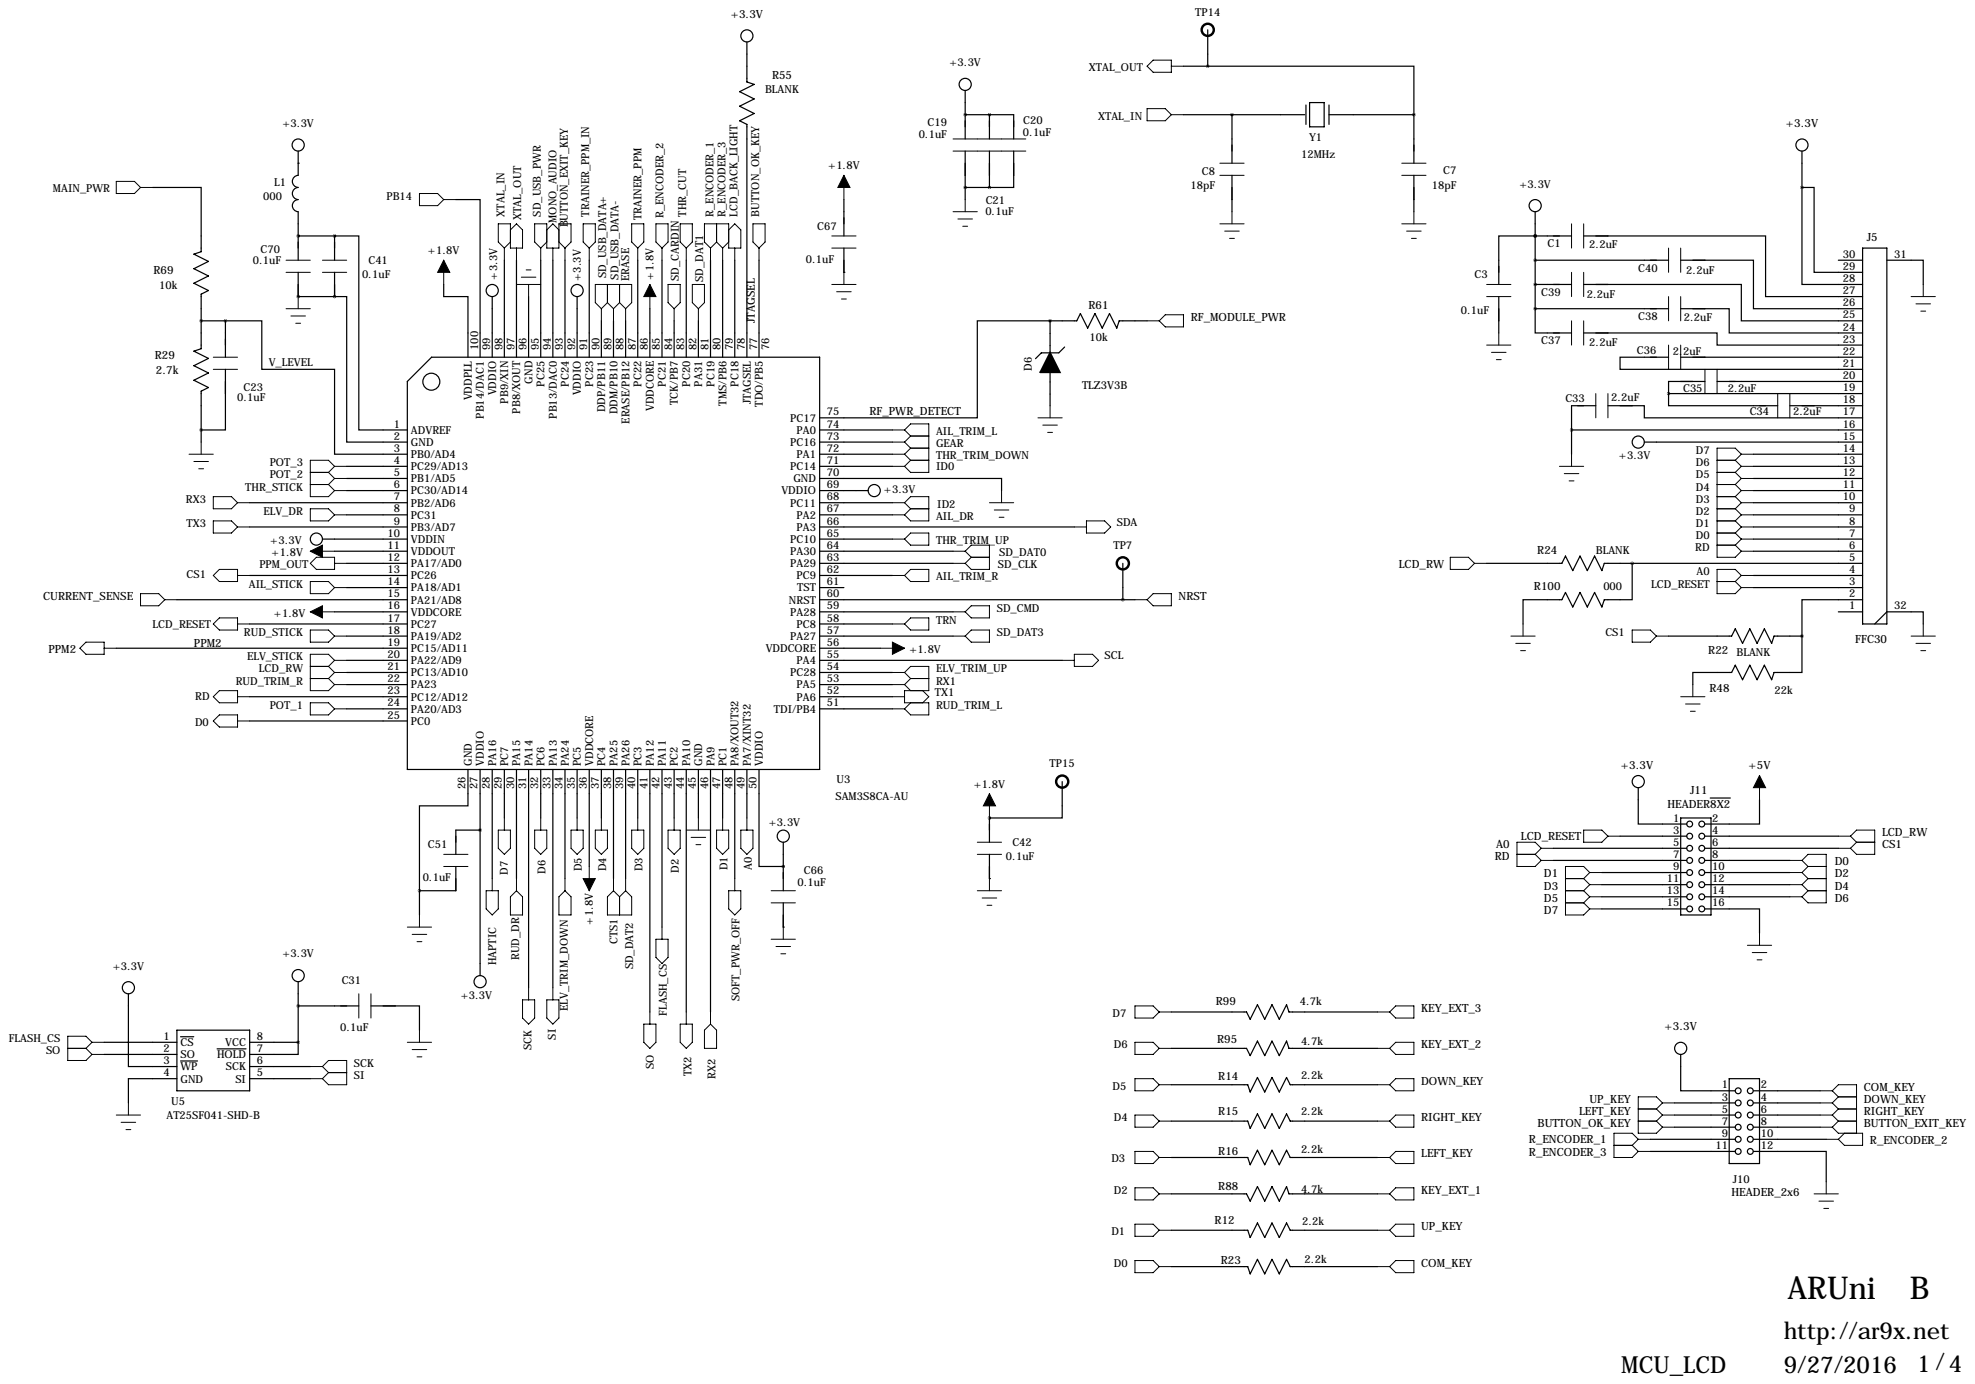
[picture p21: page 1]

76 TDO/PB5 77 JTAGSEL 78 PC18 79 TMS/PB6 80 PC19 81 PA31 82 PC20 83 TCK/PB7 84 PC21 85 VDDCORE 86 PC22 87 ERASE/PB12 88 DDM/PB10 89 DDP/PB11 90 PC23 91 VDDIO 92 PC24 93 PB13/DAC0 94 PC25 95 GND 96 PB8/XOUT 97 PB9/XIN 98 VDDIO 99 PB14/DAC1 100 VDDPLL

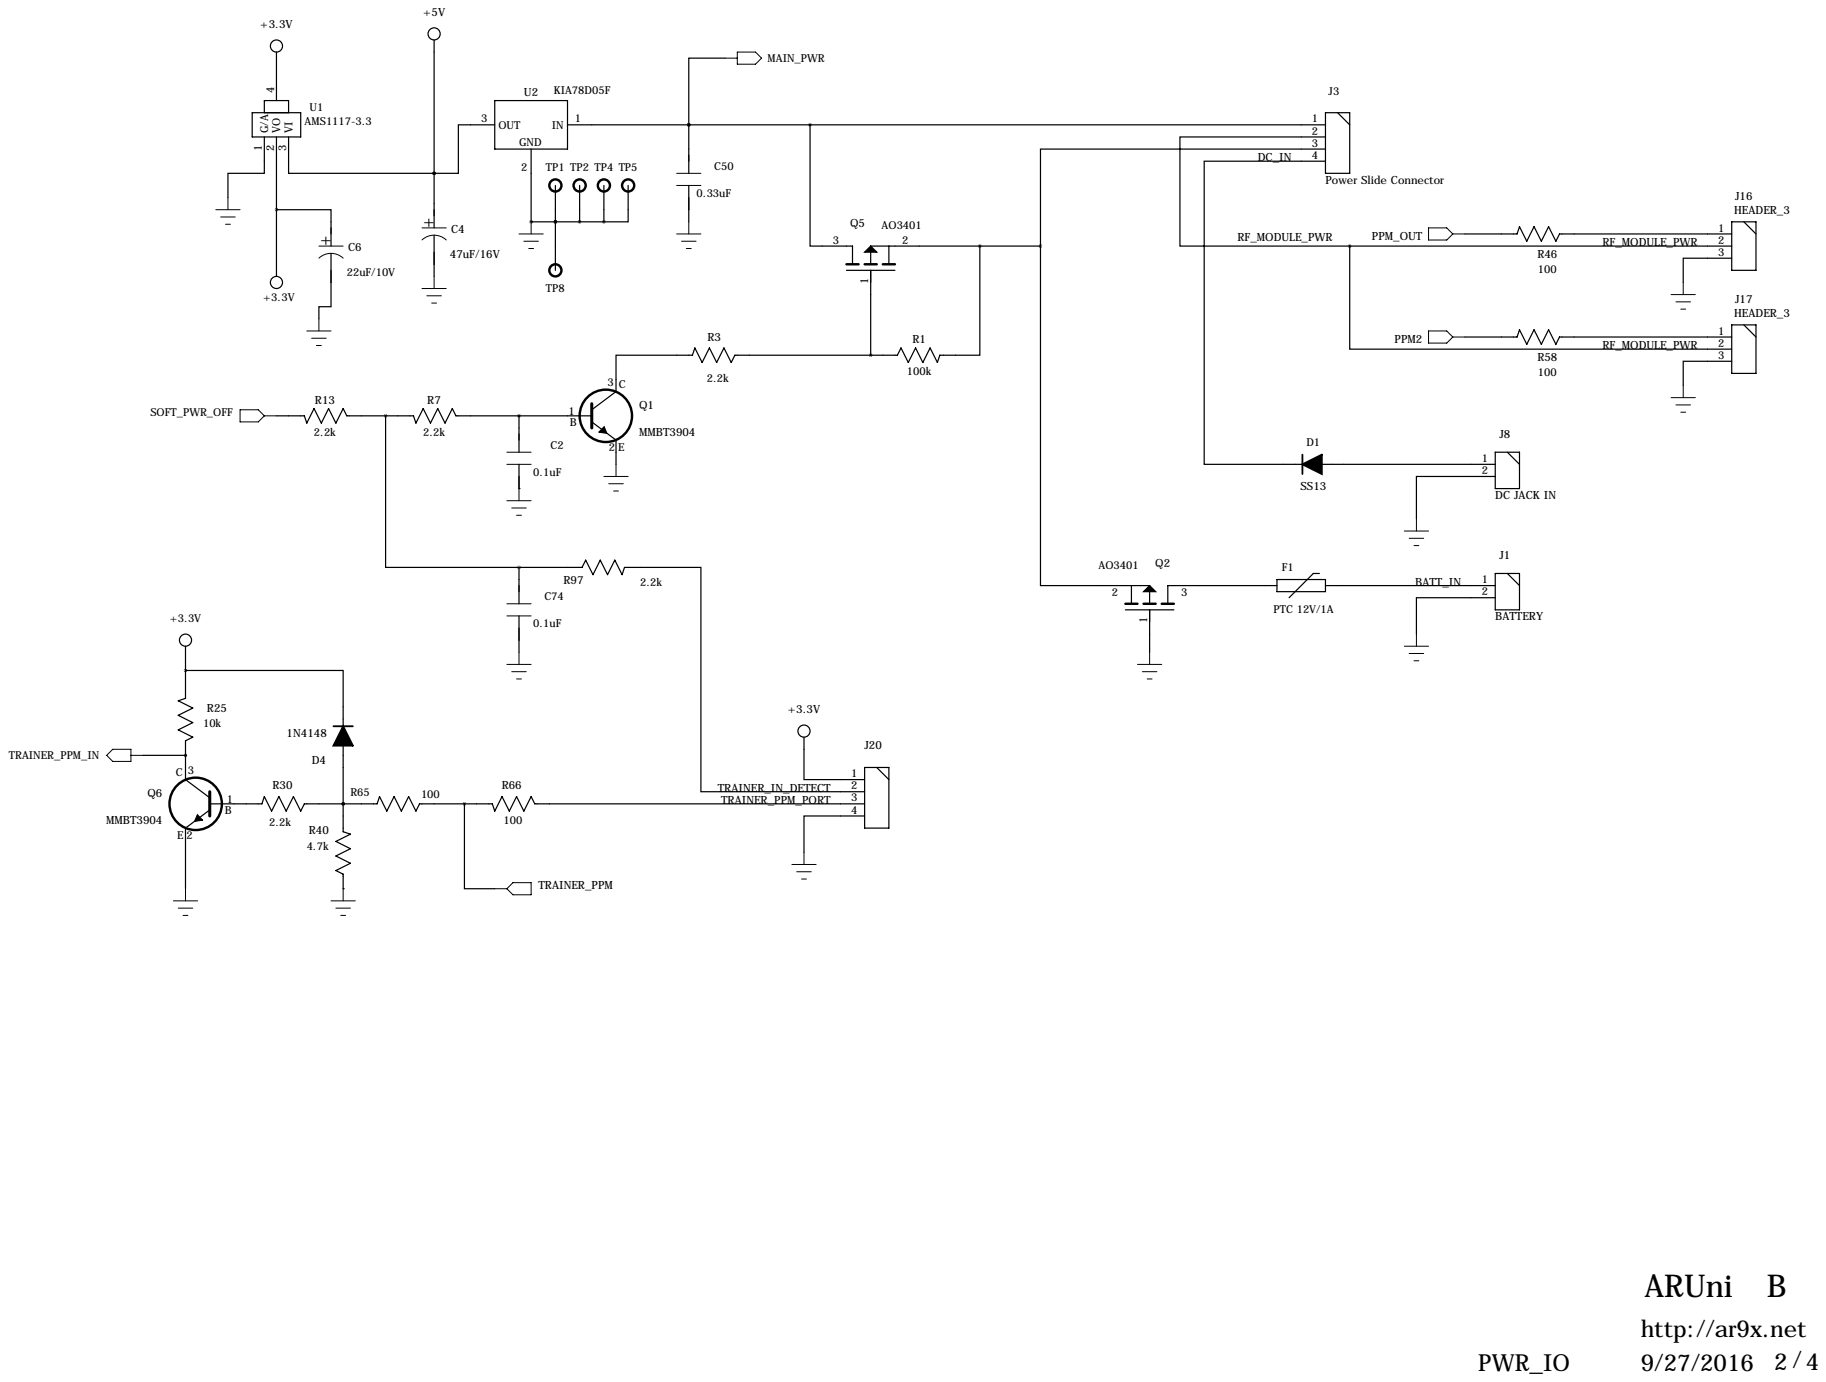
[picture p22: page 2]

# 1 Jul, Board Ver 0.5

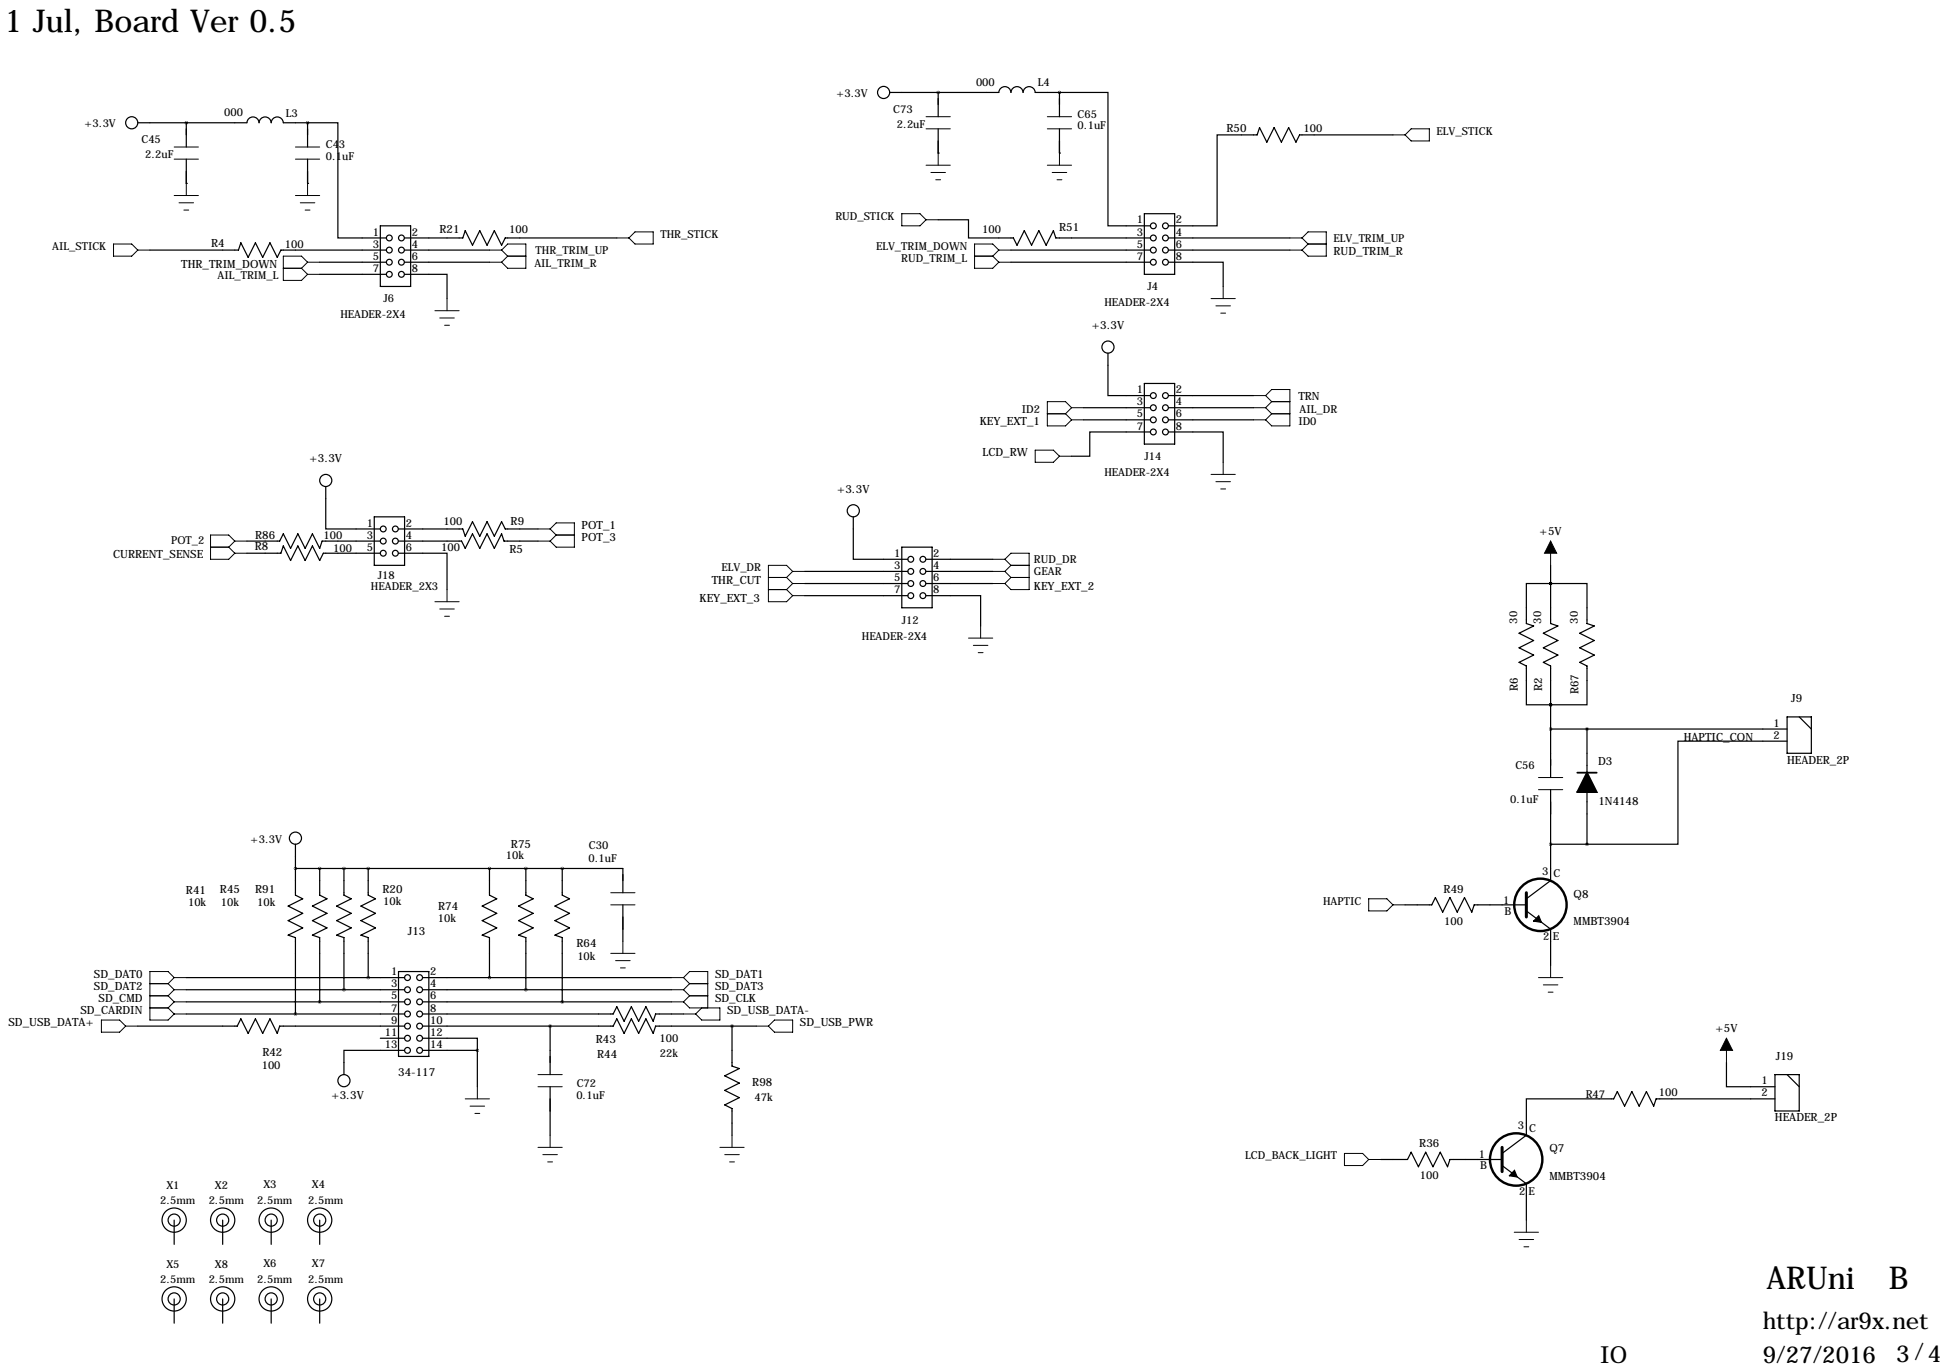
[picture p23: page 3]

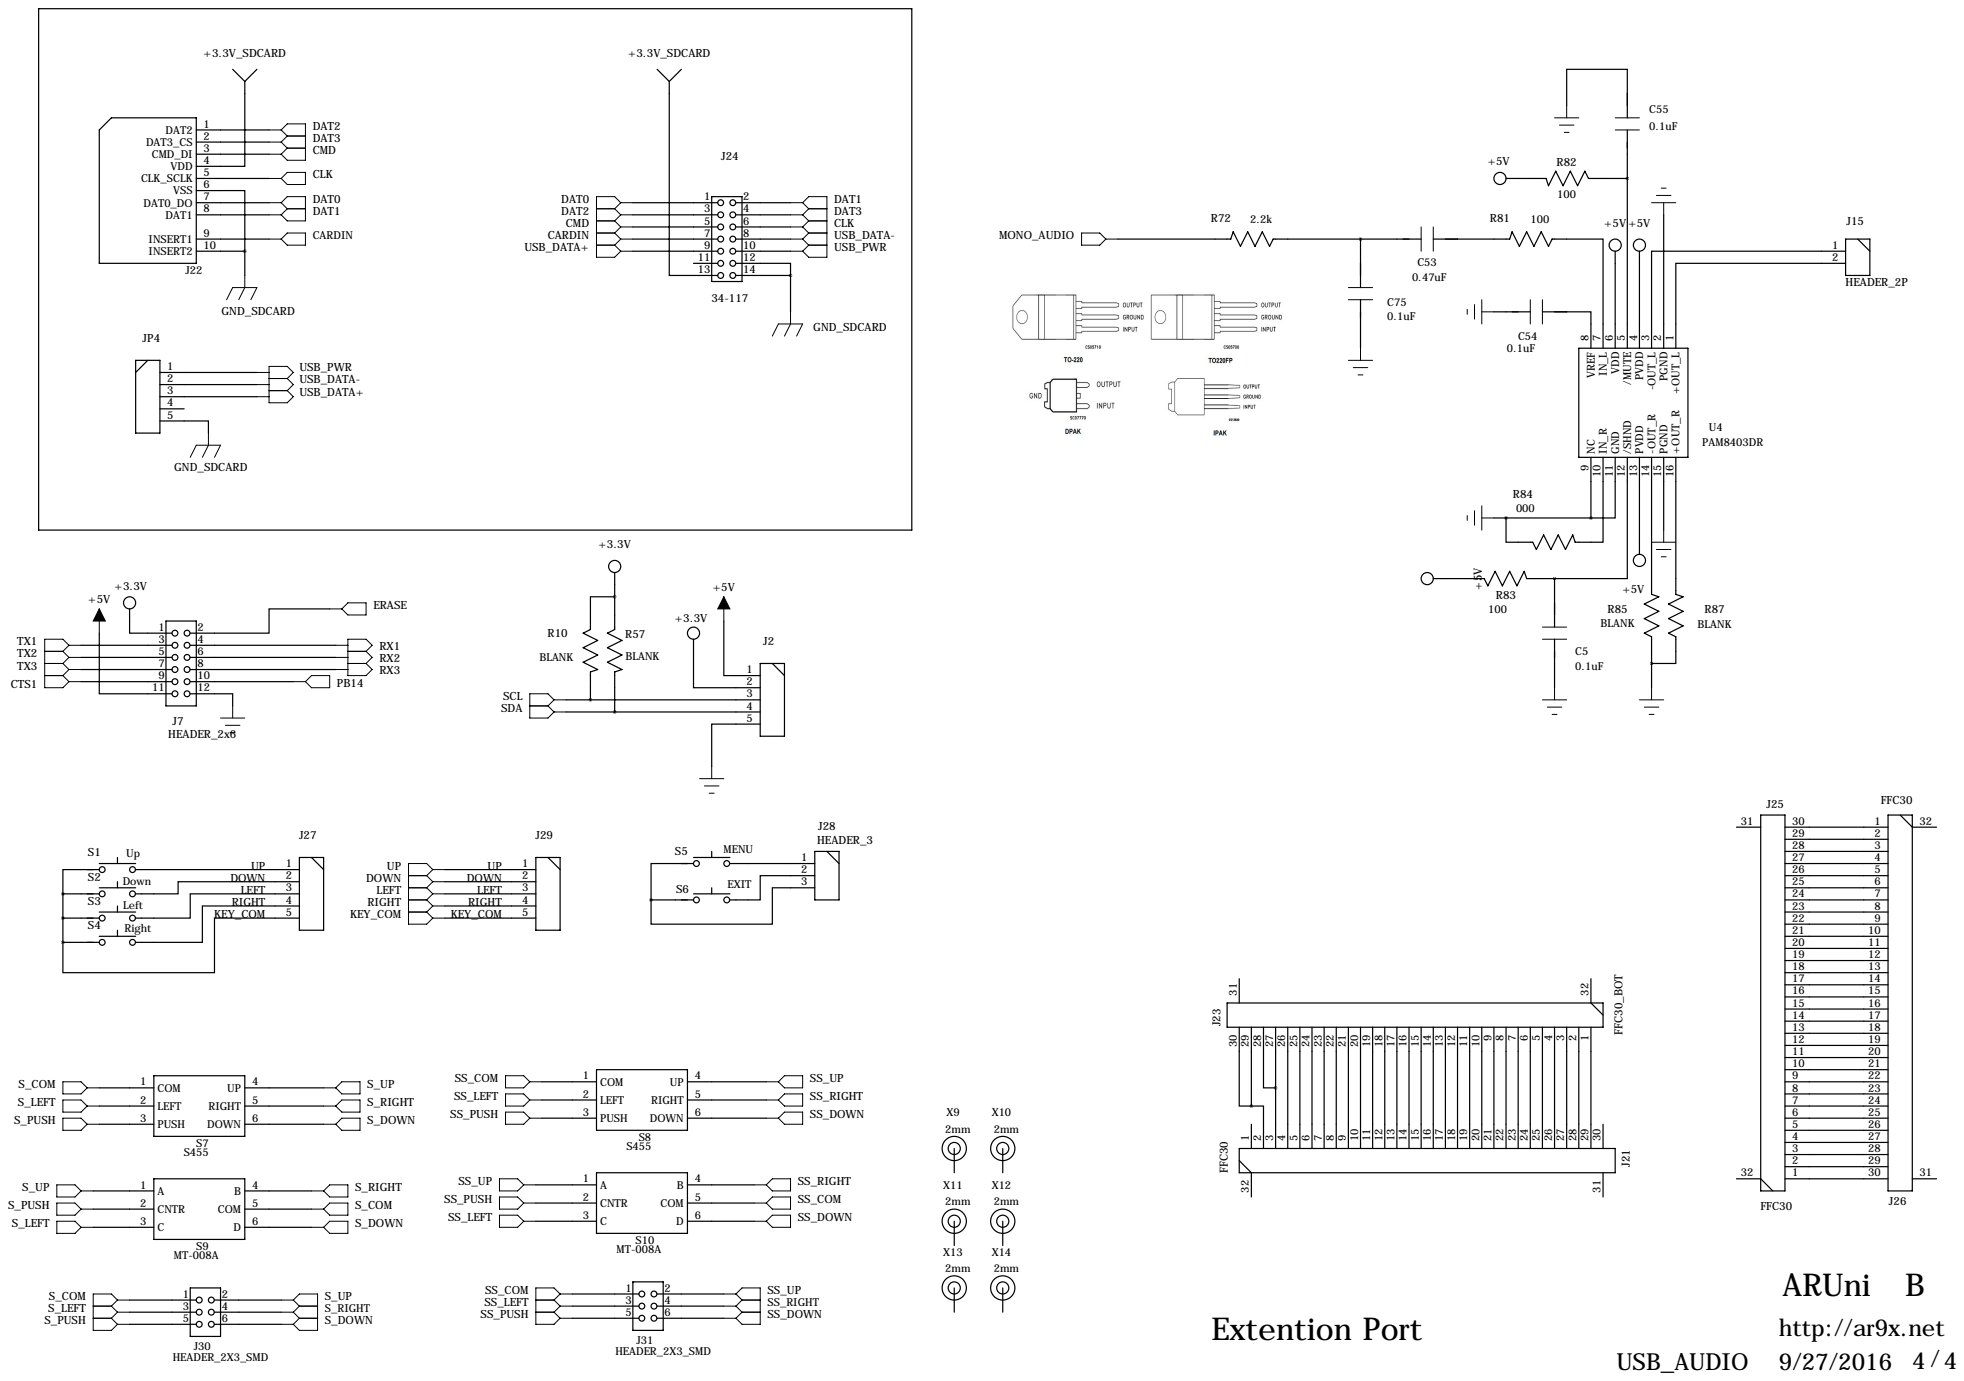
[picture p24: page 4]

9 NC 10 IN_R 11 GND 12 /SHND 13 PVDD 14 -OUT_R 15 PGND 16 +OUT_R

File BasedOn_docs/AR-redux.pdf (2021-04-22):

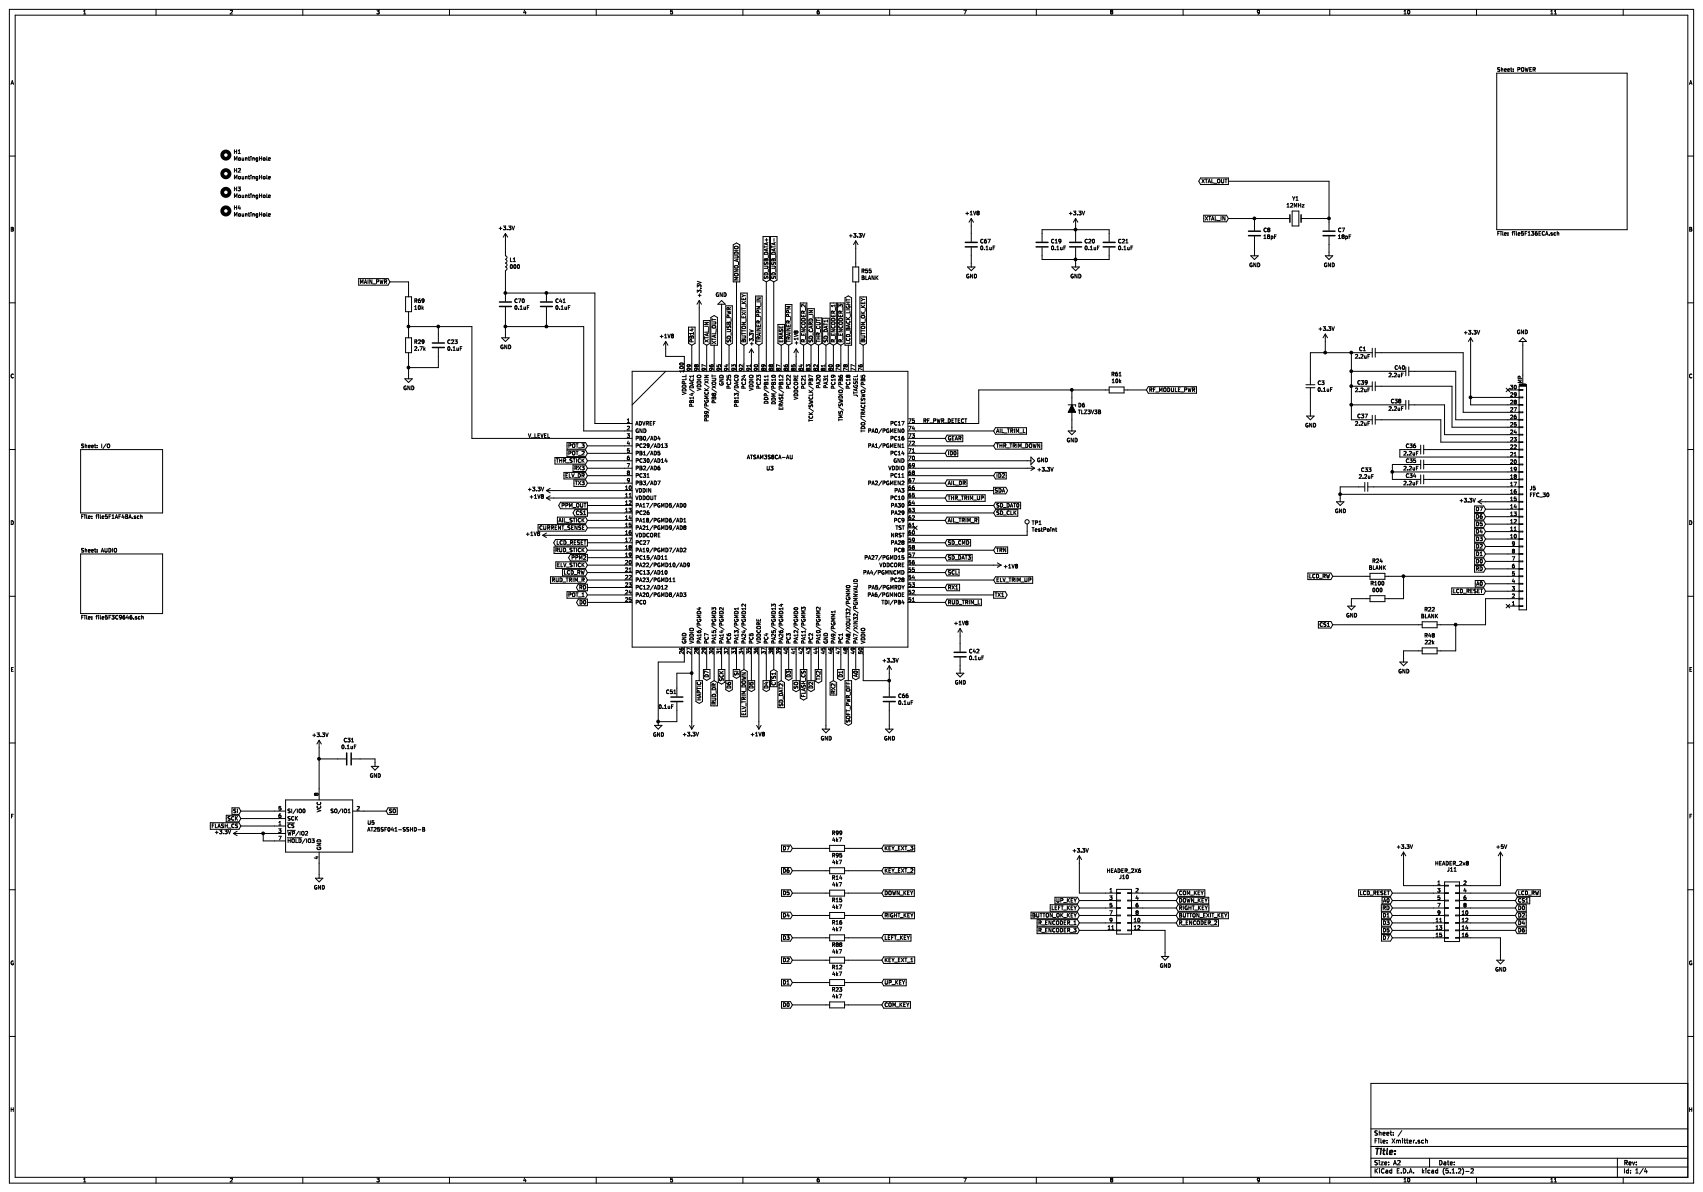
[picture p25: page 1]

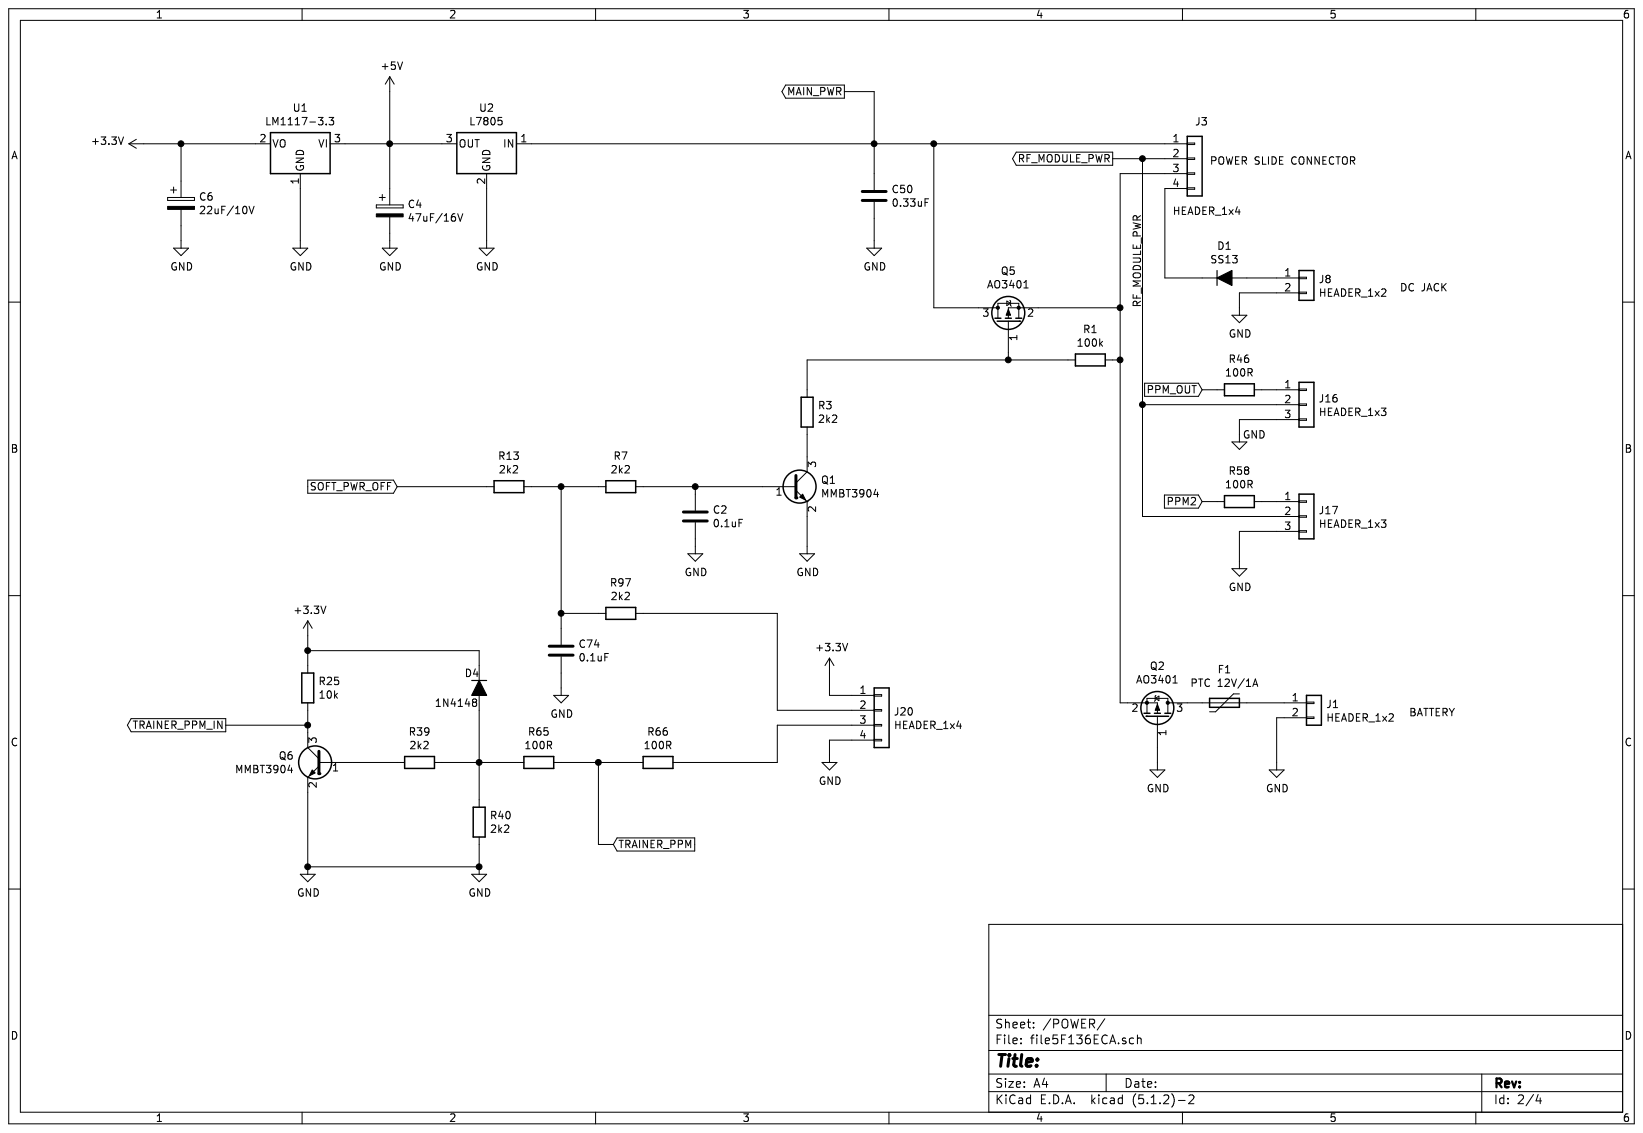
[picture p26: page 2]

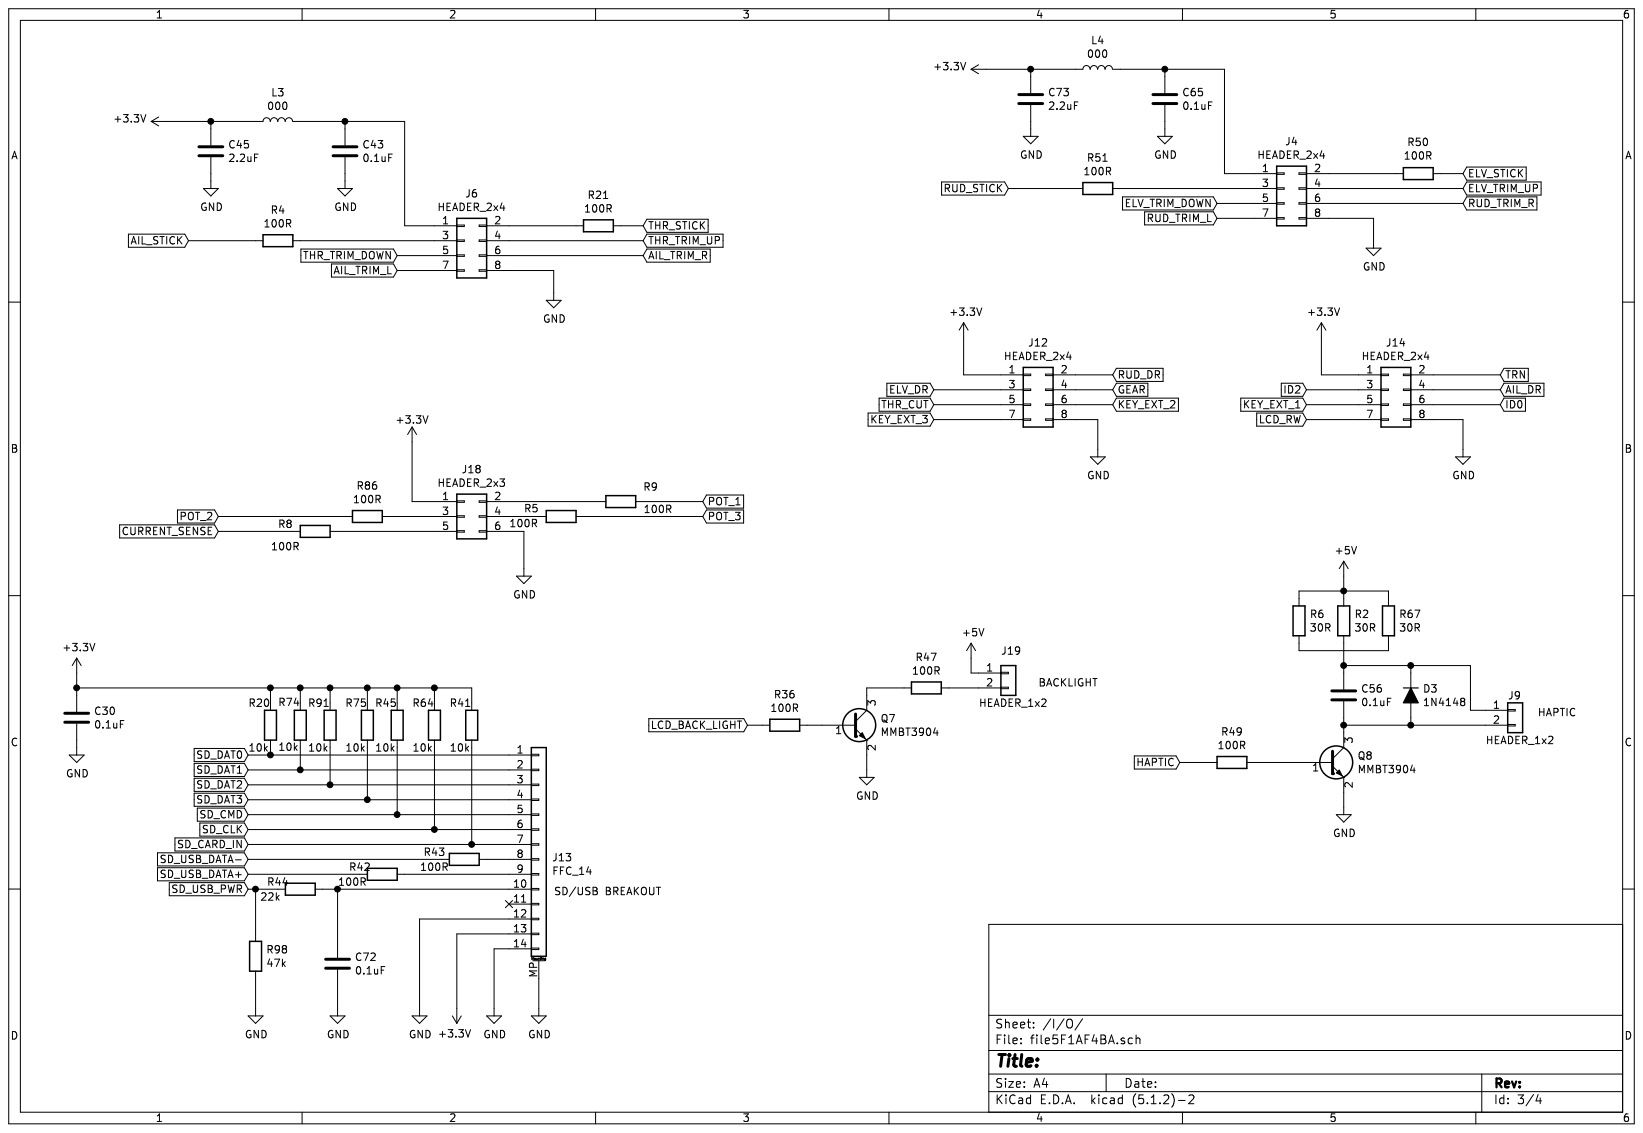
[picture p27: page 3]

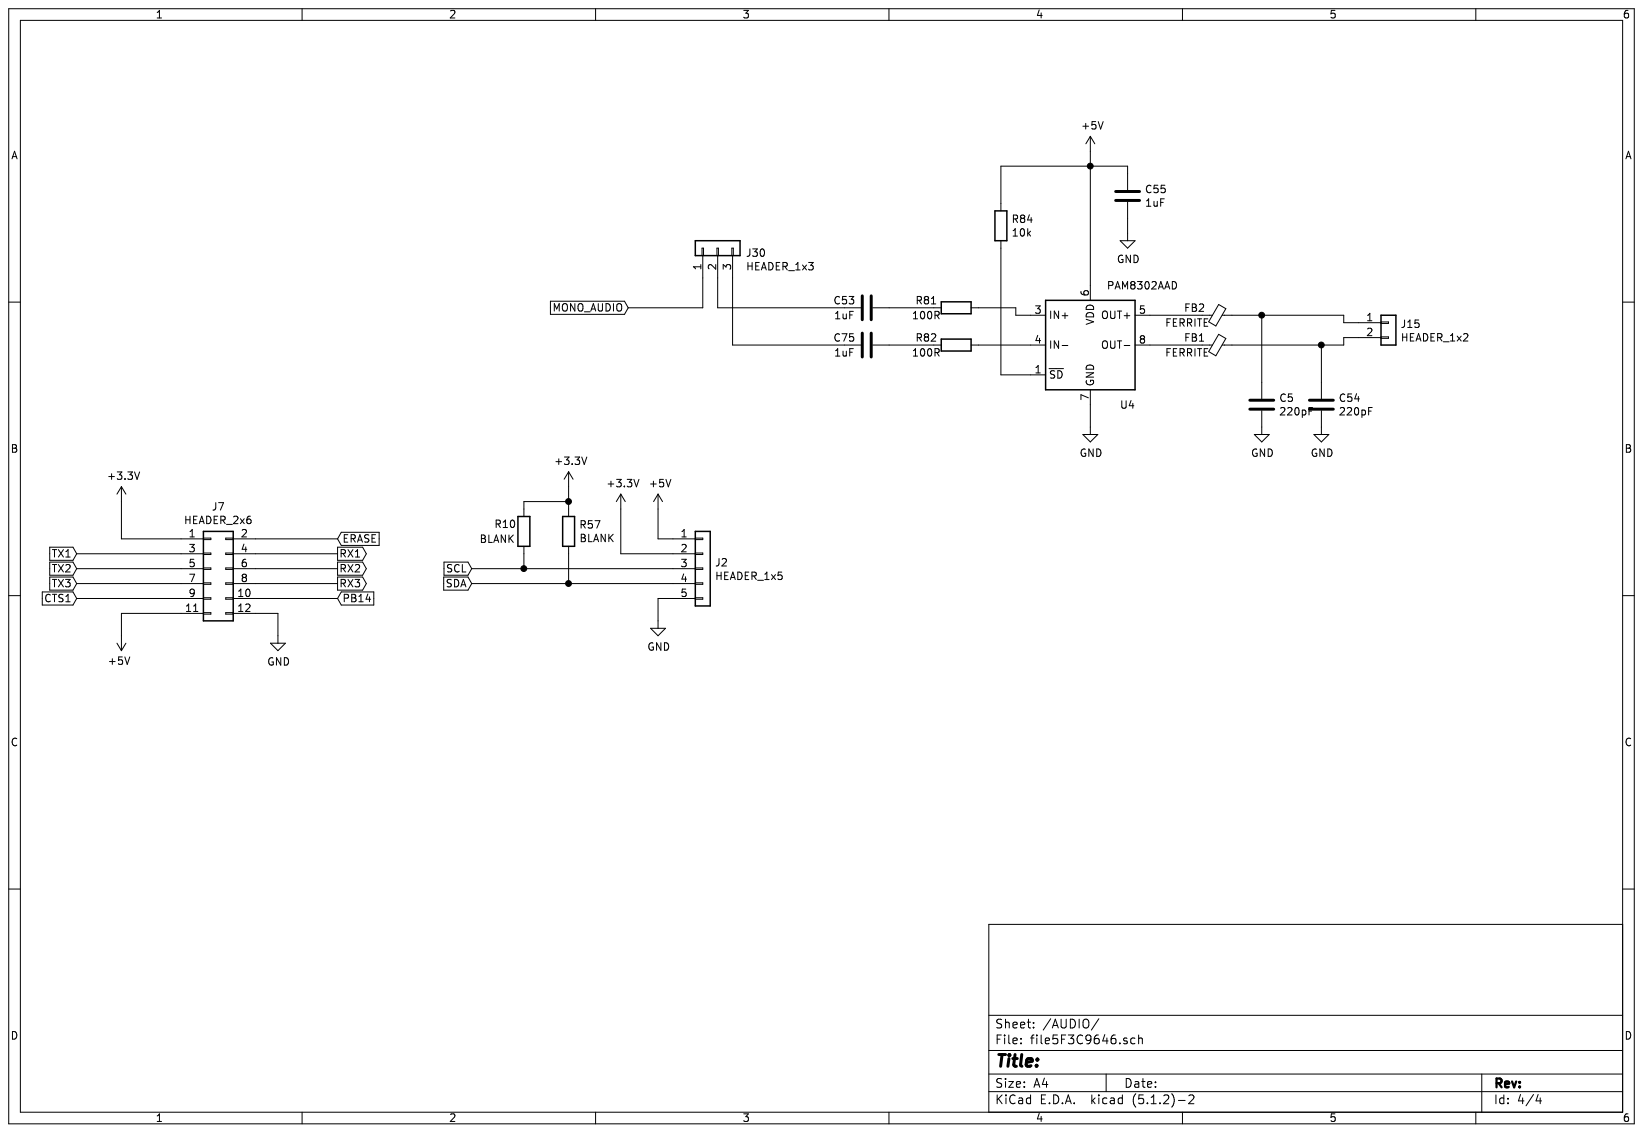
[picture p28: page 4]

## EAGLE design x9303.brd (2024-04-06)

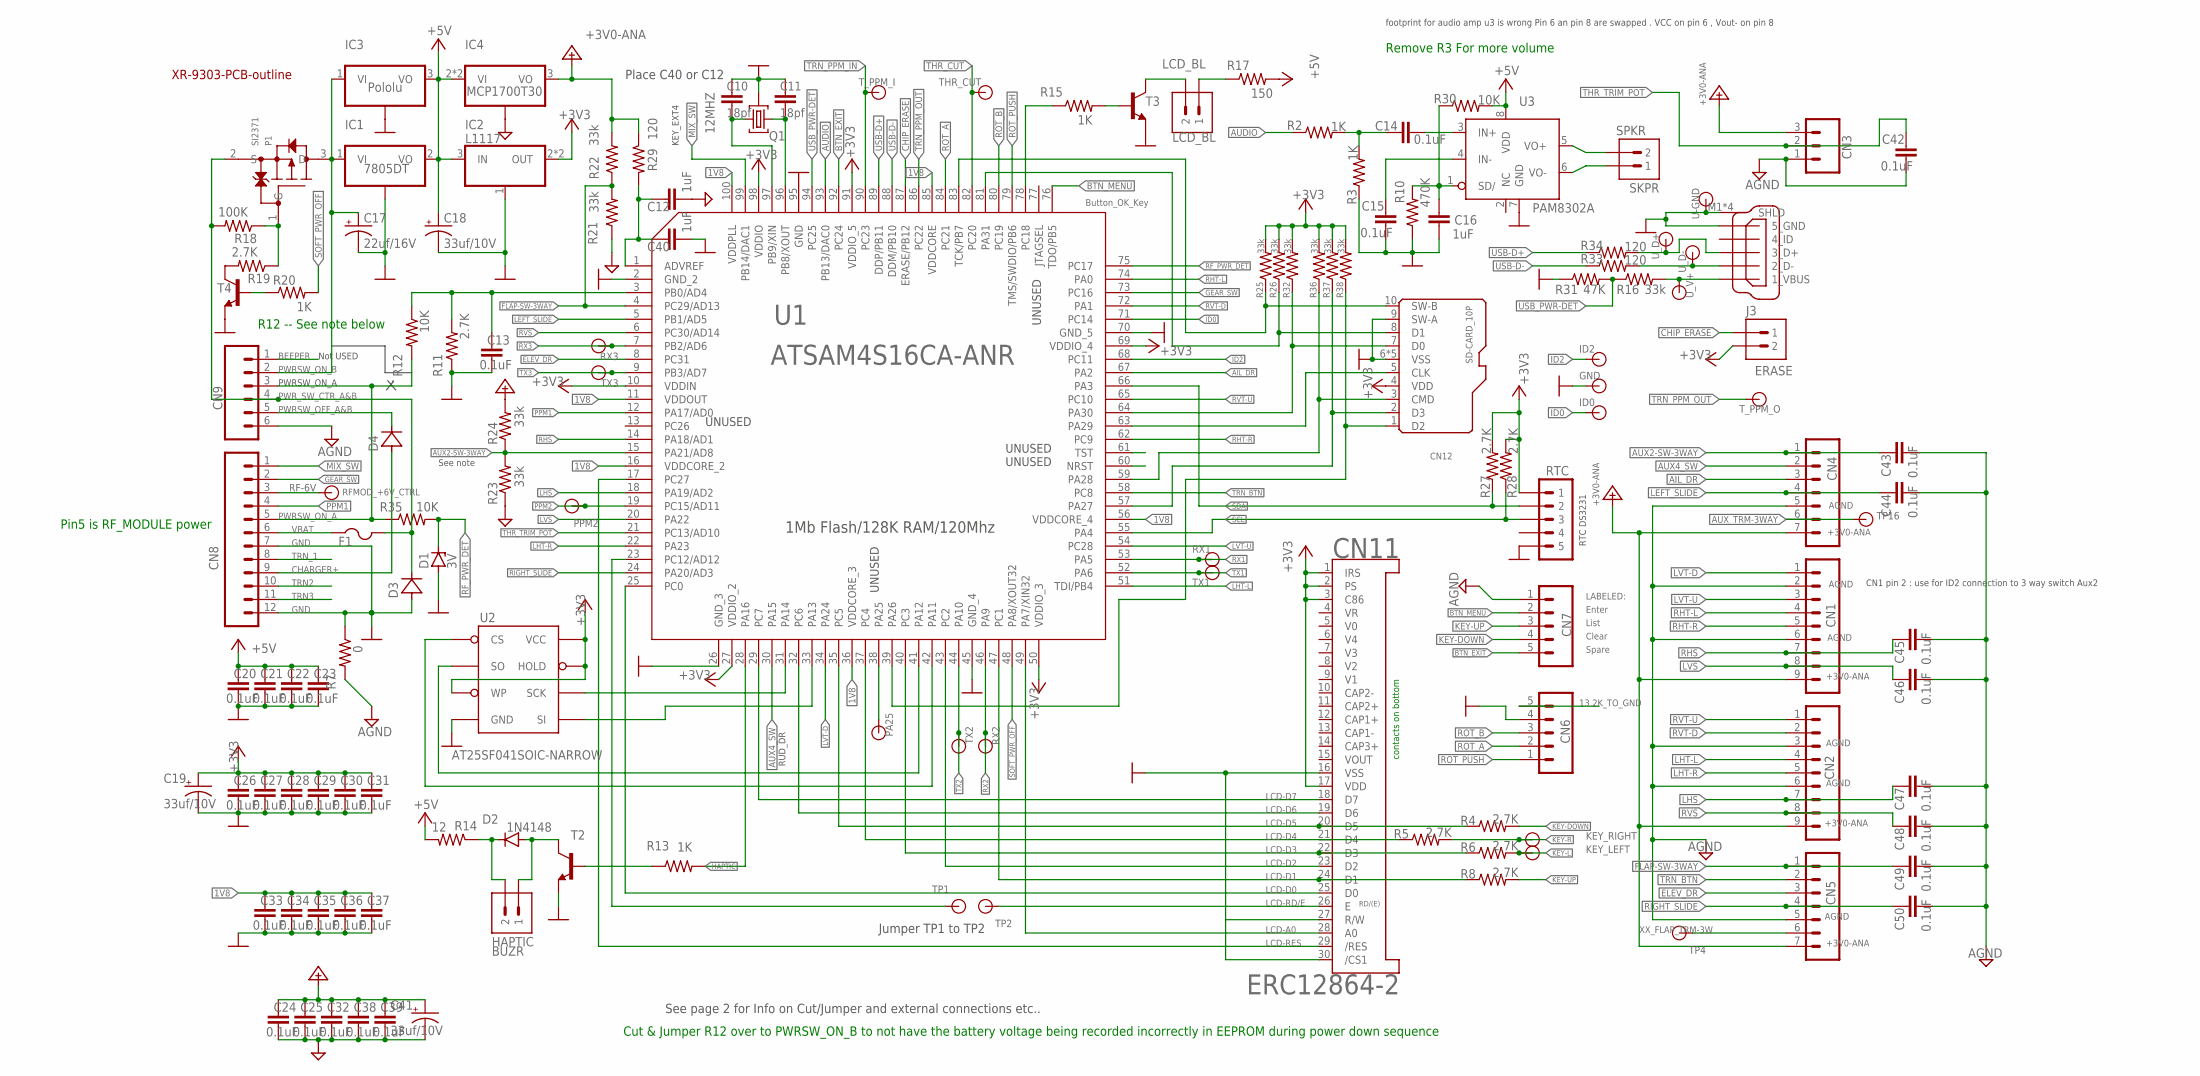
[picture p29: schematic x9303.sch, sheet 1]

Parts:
BUZR: HAPTIC; 1X02
C10, C11: 18pf; C0603K; DIGIKEY 1292-1494-1-ND
C12, C16, C40: 1uF; C0603K
C13, C14, C15, C20, C21, C22, C23, C24, C25, C26, C27, C28, C29, C30, C31, C32, C33, C34, C35, C36, C37, C38, C39, C42, C43, C44, C45, C46, C47, C48, C49, C50: 0.1uF; C0603K
C17: 22uf/16V; SMC_B; DIGIKEY 478-1758-1-ND
C18, C19, C41: 33uf/10V; SMC_B; DIGIKEY 478-9074-1-ND
CN1, CN2: CONN_09JST-9-PTH-V; JST-9-PTH-VERT
CN3: CONN_03JST-PTH-VERT; JST-3-PTH-VERT; DIGIKEY swr201-nrtn-s03-sa-wh
CN4: CONN_07JST-7PTH-V; JST-7-PTH-VERT
CN5: CONN_07JST-7PTH-V; JST-7-PTH-VERT; DIGIKEY 455-1709-ND
CN6: CONN_05JST-VERT; JST-5-PTH-VERT; DIGIKEY swr201-nrtn-s05-sa-wh
CN7: CONN_05JST-VERT; JST-5-PTH-VERT
CN8: CONN_12JST-12-PTH-V; JST-12-PTH-VERT; DIGIKEY 415-1714-ND
CN9: CONN_06JST-6-PTH-V; JST-6-PTH-VERT; DIGIKEY 455-1708-ND
CN11: ERC12864-2; FH12-30S-0.5SH
CN12: SD-CARD_10P; CONN8_DM3D-SF_HIR
D1: 3V; SOT23; DIGIKEY BZX84B3V0-FDICT-ND-Nd
D2: 1N4148; DO35-7
D3, D4: MURA220T3G; SMA
F1: SMD-FUSE-1206; R1206
GND: TP-1; TP
IC1: 7805DT; TO252
IC2: L1117; SOT223; DIGIKEY 497-17239-1-ND
IC3: Pololu; POLOLU
IC4: MCP1700T30; SOT89
ID0, ID2: TP-1; TP
J3: ERASE; 1X02
KEY_LEFT: TP-1; TP
KEY_RIGHT: TP-1; TP
LCD_BL: LCD_BL; 1X02
P1: SI2371; SOT23
PA25: TP-1; TP
PPM2: TP-1; TP
Q1: 12MHZ; XTAL2.4X2.7; DIGIKEY lfxtal083388RL3K
R2, R3, R13, R15, R20: 1K; R0603
R4, R5, R6, R8, R11, R19, R27, R28: 2.7K; R0603
R7: 0; R0805
R10: 470K; R0603
R12, R30, R35: 10K; R0603
R14: 12; R0805
R16, R21, R22, R23, R24, R25, R26, R32, R36, R37, R38: 33k; R0603
R17: 150; R0805
R18: 100K; R0603
R29, R33, R34: 120; R0603
R31: 47K; R0603
RF-6V: TP-1; TP
RTC: M05PTH; 1X05
RX1, RX2, RX3: TP-1; TP
SPKR: SKPR; 1X02
T2, T3, T4: MMBT3904; SOT23-BEC; DIGIKEY 2368-MMBT3904-ND
THR_CUT: TP-1; TP
TP1, TP2, TP4, TP16: TP-1; TP
TX1, TX2, TX3: TP-1; TP
T_PPM_I: TP-1; TP
T_PPM_O: TP-1; TP
U1: ATSAM4S16CA-ANR; TQFP100_14X14MC_MCH
U2: AT25SF041SOIC-NARROW; SO08
U3: PAM8302A; SOIC_2AADCR_DIO
U$1: XR9303-PCB; XR9303-PCB_OUTLINE
U-GND: TP-1; TP
U_D+: TP-1; TP
U_D-: TP-1; TP
U_V+: TP-1; TP
X2: MINI-USB-32005-201; 32005-201

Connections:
1V8: C33.2, C34.2, C35.2, C36.2, C37.2, U1.11 (VDDOUT), U1.16 (VDDCORE_2), U1.36 (VDDCORE_3), U1.56 (VDDCORE_4), U1.85 (VDDCORE), U1.100 (VDDPLL)
13.2K_TO_GND: CN6.5
+3V0-ANA: C24.2, C25.2, C32.2, C38.2, C39.2, C41.+, CN1.9, CN2.9, CN3.3, CN4.7, CN5.7, IC4.3 (VO), R22.2, R24.2, R29.1
+3V3: C19.+, C26.2, C27.2, C28.2, C29.2, C30.2, C31.2, CN11.1 (IRS), CN11.2 (PS), CN11.3 (C86), CN11.17 (VDD), CN12.4 (VDD), IC2.2 (OUT), IC2.4 (OUT), J3.2, R25.2, R26.2, R27.2, R28.2, R32.2, R36.2, R37.2, R38.2, RTC.1, U1.10 (VDDIN), U1.27 (VDDIO_2), U1.50 (VDDIO_3), U1.69 (VDDIO_4), U1.91 (VDDIO_5), U1.98 (VDDIO), U2.3 (WP), U2.7 (HOLD), U2.8 (VCC)
+5V: C18.+, C20.2, C21.2, C22.2, C23.2, IC1.2 (VO), IC2.3 (IN), IC3.3 (VO), IC4.2 (VI), IC4.4 (VI), R14.2, R17.2, R30.2, U3.8 (VDD)
AGND: C12.2, C24.1, C25.1, C32.1, C38.1, C39.1, C41.-, C42.1, C43.1, C44.1, C45.1, C46.1, C47.1, C48.1, C49.1, C50.1, CN1.2, CN1.6, CN2.3, CN2.6, CN3.1, CN4.5, CN5.5, CN7.1, CN9.6, IC4.1 (GND), R7.2, R21.1, R23.1
AIL_DR: CN4.3, U1.67 (PA2)
AUDIO: R2.1, U1.93 (PB13/DAC0)
AUX2-SW-3WAY: C43.2, CN4.1, R23.2, R24.1, U1.15 (PA21/AD8)
AUX4_SW: CN4.2, U1.30 (PA15)
AUX_TRM-3WAY: CN4.6, TP16.P$1
BEEPER: CN9.1
BTN_EXIT: CN7.5, U1.92 (PC24)
BTN_MENU: CN7.2, U1.76 (TDO/PB5)
CHARGER+: CN8.9, D4.A
CHIP_ERASE: J3.1, U1.87 (ERASE/PB12)
ELEV_DR: CN5.3, U1.8 (PC31)
FLAP-SW-3WAY: C49.2, CN5.1, R21.2, R22.1, U1.4 (PC29/AD13)
FLASH_CS: U1.42 (PA11), U2.1 (CS)
GEAR_SW: CN8.2, U1.73 (PC16)
GND: C10.1, C11.1, C13.1, C15.1, C16.2, C17.-, C18.-, C19.-, C20.1, C21.1, C22.1, C23.1, C26.1, C27.1, C28.1, C29.1, C30.1, C31.1, C33.1, C34.1, C35.1, C36.1, C37.1, C40.2, CN6.4, CN8.7, CN8.12, CN11.16 (VSS), CN11.27 (R/W), CN11.30 (/CS1), CN12.6 (VSS), CN12.9 (SW-A), CN12.GND1 (VSS), CN12.GND2 (VSS), CN12.GND3 (VSS), CN12.GND4 (VSS), D1.1 (A), D3.A, GND.P$1, IC1.3 (GND), IC2.1 (GND), IC3.2 (GND), Q1.P$2 (2), Q1.P$4 (2), R3.1, R7.1, R10.1, R11.1, R31.1, RTC.5, T2.E, T3.E, T4.E, U1.2 (GND_2), U1.26 (GND_3), U1.45 (GND_4), U1.70 (GND_5), U1.95 (GND), U2.4 (GND), U3.7 (GND), U-GND.P$1, X2.5_USB_GND (5_GND), X2.M1 (SHLD), X2.M2 (SHLD), X2.M3 (SHLD), X2.M4 (SHLD)
HAPTIC: R13.2, U1.28 (PA16)
ID0: ID0.P$1, U1.71 (PC14)
ID2: ID2.P$1, U1.68 (PC11)
KEY-DOWN: CN7.4, R4.2
KEY-L: KEY_LEFT.P$1, R6.2
KEY-R: KEY_RIGHT.P$1, R5.2
KEY-UP: CN7.3, R8.2
LCD-A0: CN11.28 (A0), U1.49 (PA7/XIN32)
LCD-D0: CN11.25 (D0), U1.25 (PC0)
LCD-D1: CN11.24 (D1), R8.1, U1.47 (PC1)
LCD-D2: CN11.23 (D2), U1.43 (PC2)
LCD-D3: CN11.22 (D3), R6.1, U1.40 (PC3)
LCD-D4: CN11.21 (D4), R5.1, U1.37 (PC4)
LCD-D5: CN11.20 (D5), R4.1, U1.35 (PC5)
LCD-D6: CN11.19 (D6), U1.32 (PC6)
LCD-D7: CN11.18 (D7), U1.29 (PC7)
LCD-RD/E: CN11.26 (E), TP2.P$1
LCD-RES: CN11.29 (/RES), U1.17 (PC27)
LCD_BL: R15.1, U1.78 (PC18)
LEFT_SLIDE: C44.2, CN4.4, U1.5 (PB1/AD5)
LHS: C47.2, CN2.7, U1.18 (PA19/AD2)
LHT-L: CN2.4, U1.51 (TDI/PB4)
LHT-R: CN2.5, U1.22 (PA23)
LVS: C46.2, CN1.8, U1.20 (PA22)
LVT-D: CN1.1, U1.34 (PA24)
LVT-U: CN1.3, U1.54 (PC28)
MIX_SW: CN8.1, U1.99 (PB14/DAC1)
unnamed: C16.1, R10.2, R30.1, U3.1 (SD/)
unnamed: R16.2, U_V+.P$1, X2.1_VBUS
unnamed: P1.1 (G), R18.1, R19.1
unnamed: R19.2, T4.C
unnamed: R34.2, U_D+.P$1, X2.3_D+
unnamed: C14.1, R2.2, R3.2
unnamed: R20.1, T4.B
unnamed: BUZR.2, D2.C, R14.1
unnamed: TP1.P$1, U1.23 (PC12/AD12)
unnamed: U1.31 (PA14), U2.6 (SCK)
unnamed: U1.33 (PA13), U2.5 (SI)
unnamed: PA25.P$1, U1.38 (PA25)
unnamed: U1.41 (PA12), U2.2 (SO)
unnamed: C10.2, Q1.P$3 (3), U1.97 (PB9/XIN)
unnamed: C11.2, Q1.P$1 (1), U1.96 (PB8/XOUT)
unnamed: CN12.8 (D1), R26.1, U1.81 (PA31)
unnamed: CN12.10 (SW-B), R25.1, U1.83 (TCK/PB7)
unnamed: CN12.7 (D0), R32.1, U1.64 (PA30)
unnamed: CN12.5 (CLK), U1.63 (PA29)
unnamed: R13.1, T2.B
unnamed: CN12.2 (D3), R37.1, U1.57 (PA27)
unnamed: CN12.1 (D2), R38.1, U1.39 (PA26)
unnamed: SPKR.2, U3.5 (VO+)
unnamed: BUZR.1, D2.A, T2.C
unnamed: R15.2, T3.B
unnamed: LCD_BL.2, T3.C
unnamed: LCD_BL.1, R17.1
unnamed: C12.1, C40.1, R29.2, U1.1 (ADVREF)
unnamed: CN12.3 (CMD), R36.1, U1.59 (PA28)
unnamed: SPKR.1, U3.6 (VO-)
unnamed: C14.2, U3.3 (IN+)
unnamed: C15.2, U3.4 (IN-)
PPM1: CN8.4, U1.12 (PA17/AD0)
PPM2: PPM2.P$1, U1.19 (PC15/AD11)
PWRSW_OFF_A&B: CN9.5, D4.C
PWRSW_ON_A: CN8.5, CN9.3, R12.2, R35.1
PWRSW_ON_B: C17.+, CN9.2, IC1.1 (VI), IC3.1 (VI), P1.3 (D)
PWR_SW_CTR_A&B: CN9.4, D3.C, F1.2, P1.2 (S), R18.2
RFMOD_+6V_CTRL: CN8.3, RF-6V.P$1
RF_PWR_DET: D1.3 (C), R35.2, U1.75 (PC17)
RHS: C45.2, CN1.7, U1.14 (PA18/AD1)
RHT-L: CN1.4, U1.74 (PA0)
RHT-R: CN1.5, U1.62 (PC9)
RIGHT_SLIDE: C50.2, CN5.4, U1.24 (PA20/AD3)
ROT_A: CN6.2, U1.84 (PC21)
ROT_B: CN6.3, U1.80 (PC19)
ROT_PUSH: CN6.1, U1.79 (TMS/SWDIO/PB6)
RVS: C48.2, CN2.8, U1.6 (PC30/AD14)
RVT-D: CN2.2, U1.72 (PA1)
RVT-U: CN2.1, U1.65 (PC10)
RX1: RX1.P$1, U1.53 (PA5)
RX2: RX2.P$1, U1.46 (PA9)
RX3: RX3.P$1, U1.7 (PB2/AD6)
SCL: R28.1, RTC.3, U1.55 (PA4)
SDA: R27.1, RTC.2, U1.66 (PA3)
SOFT_PWR_OFF: R20.2, U1.48 (PA8/XOUT32)
THR_CUT: THR_CUT.P$1, U1.82 (PC20)
THR_TRIM_POT: C42.2, CN3.2, U1.21 (PC13/AD10)
TRN2: CN8.10
TRN3: CN8.11
TRN_1: CN8.8
TRN_BTN: CN5.2, U1.58 (PC8)
TRN_PPM_IN: T_PPM_I.P$1, U1.90 (PC23)
TRN_PPM_OUT: T_PPM_O.P$1, U1.86 (PC22)
TX1: TX1.P$1, U1.52 (PA6)
TX2: TX2.P$1, U1.44 (PA10)
TX3: TX3.P$1, U1.9 (PB3/AD7)
USB-D+: R34.1, U1.89 (DDP/PB11)
USB-D-: R33.1, U1.88 (DDM/PB10)
USB_D-: R33.2, U_D-.P$1, X2.2_D-
USB_PWR-DET: R16.1, R31.2, U1.94 (PC25)
VBAT: CN8.6, F1.1
VBAT_MEAS: C13.2, R11.2, R12.1, U1.3 (PB0/AD4)
XX_FLAP_TRM-3W: CN5.6, TP4.P$1

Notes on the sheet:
LABELED:
Enter
List
Clear
Spare
Button_OK_Key
RD/(E)
RTC DS3231
1Mb Flash/128K RAM/120Mhz
RUD_DR
KEY_EXT4
UNUSED
Not USED
PWRSW_ON_A
Place C40 or C12
Jumper TP1 to TP2
See note
footprint for audio amp u3 is wrong Pin 6 an pin 8 are swapped . VCC on pin 6 , Vout- on pin 8
CN1 pin 2 : use for ID2 connection to 3 way switch Aux2
See page 2 for Info on Cut/Jumper and external connections etc..
contacts on bottom
Cut & Jumper R12 over to PWRSW_ON_B to not have the battery voltage being recorded incorrectly in EEPROM during power down sequence
R12 -- See note below
Pin5 is RF_MODULE power
Remove R3 For more volume

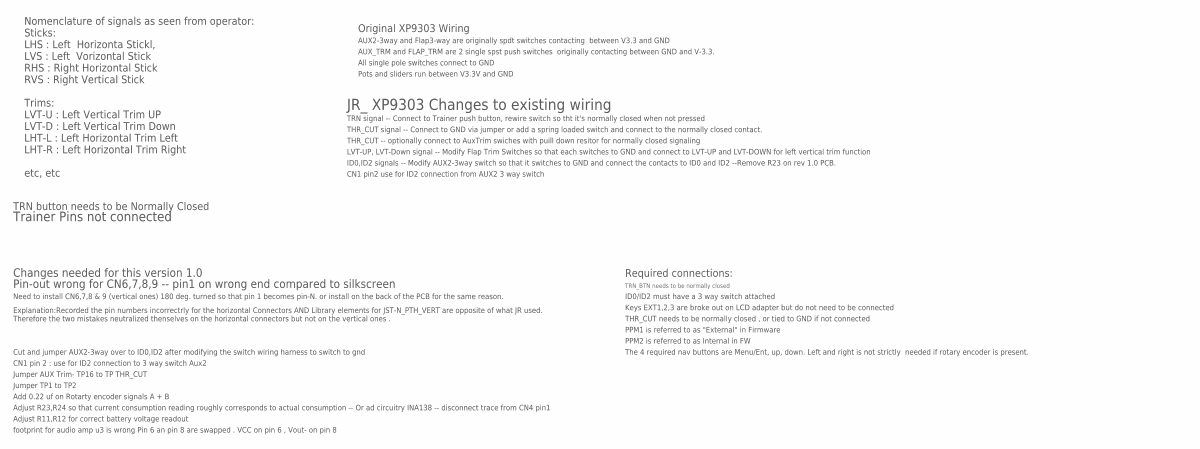
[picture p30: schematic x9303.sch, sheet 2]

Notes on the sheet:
Nomenclature of signals as seen from operator: Sticks: LHS : Left Horizonta Stickl, LVS : Left Vorizontal Stick RHS : Right Horizontal Stick RVS : Right Vertical Stick Trims: LVT-U : Left Vertical Trim UP LVT-D : Left Vertical Trim Down LHT-L : Left Horizontal Trim Left LHT-R : Left Horizontal Trim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
AUX_TRM and FLAP_TRM are 2 single spst push switches originally contacting between GND and V-3.3.
JR_ XP9303 Changes to existing wiring
All single pole switches connect to GND
Pots and sliders run between V3.3V and GND
THR_CUT signal -- Connect to GND via jumper or add a spring loaded switch and connect to the normally closed contact.
Trainer Pins not connected
TRN button needs to be Normally Closed
AUX2-3way and Flap3-way are originally spdt switches contacting between V3.3 and GND
TRN signal -- Connect to Trainer push button, rewire switch so tht it's normally closed when not pressed
LVT-UP, LVT-Down signal -- Modify Flap Trim Switches so that each switches to GND and connect to LVT-UP and LVT-DOWN for left vertical trim function
ID0,ID2 signals -- Modify AUX2-3way switch so that it switches to GND and connect the contacts to ID0 and ID2 --Remove R23 on rev 1.0 PCB.
THR_CUT -- optionally connect to AuxTrim swiches with puill down resitor for normally closed signaling
CN1 pin2 use for ID2 connection from AUX2 3 way switch
Original XP9303 Wiring
Changes needed for this version 1.0
Pin-out wrong for CN6,7,8,9 -- pin1 on wrong end compared to silkscreen
Cut and jumper AUX2-3way over to ID0,ID2 after modifying the switch wiring harness to switch to gnd
Jumper AUX Trim- TP16 to TP THR_CUT
footprint for audio amp u3 is wrong Pin 6 an pin 8 are swapped . VCC on pin 6 , Vout- on pin 8
CN1 pin 2 : use for ID2 connection to 3 way switch Aux2
Add 0.22 uf on Rotarty encoder signals A + B
Jumper TP1 to TP2
Adjust R11,R12 for correct battery voltage readout
Adjust R23,R24 so that current consumption reading roughly corresponds to actual consumption -- Or ad circuitry INA138 -- disconnect trace from CN4 pin1
Need to install CN6,7,8 & 9 (vertical ones) 180 deg. turned so that pin 1 becomes pin-N. or install on the back of the PCB for the same reason.
Explanation:Recorded the pin numbers incorrectrly for the horizontal Connectors AND Library elements for JST-N_PTH_VERT are opposite of what JR used. Therefore the two mistakes neutralized thenselves on the horizontal connectors but not on the vertical ones .
TRN_BTN needs to be normally closed
Keys EXT1,2,3 are broke out on LCD adapter but do not need to be connected
ID0/ID2 must have a 3 way switch attached
Required connections:
THR_CUT needs to be normally closed , or tied to GND if not connected
PPM1 is referred to as "External" in Firmware
PPM2 is referred to as Internal in FW
The 4 required nav buttons are Menu/Ent, up, down. Left and right is not strictly needed if rotary encoder is present.

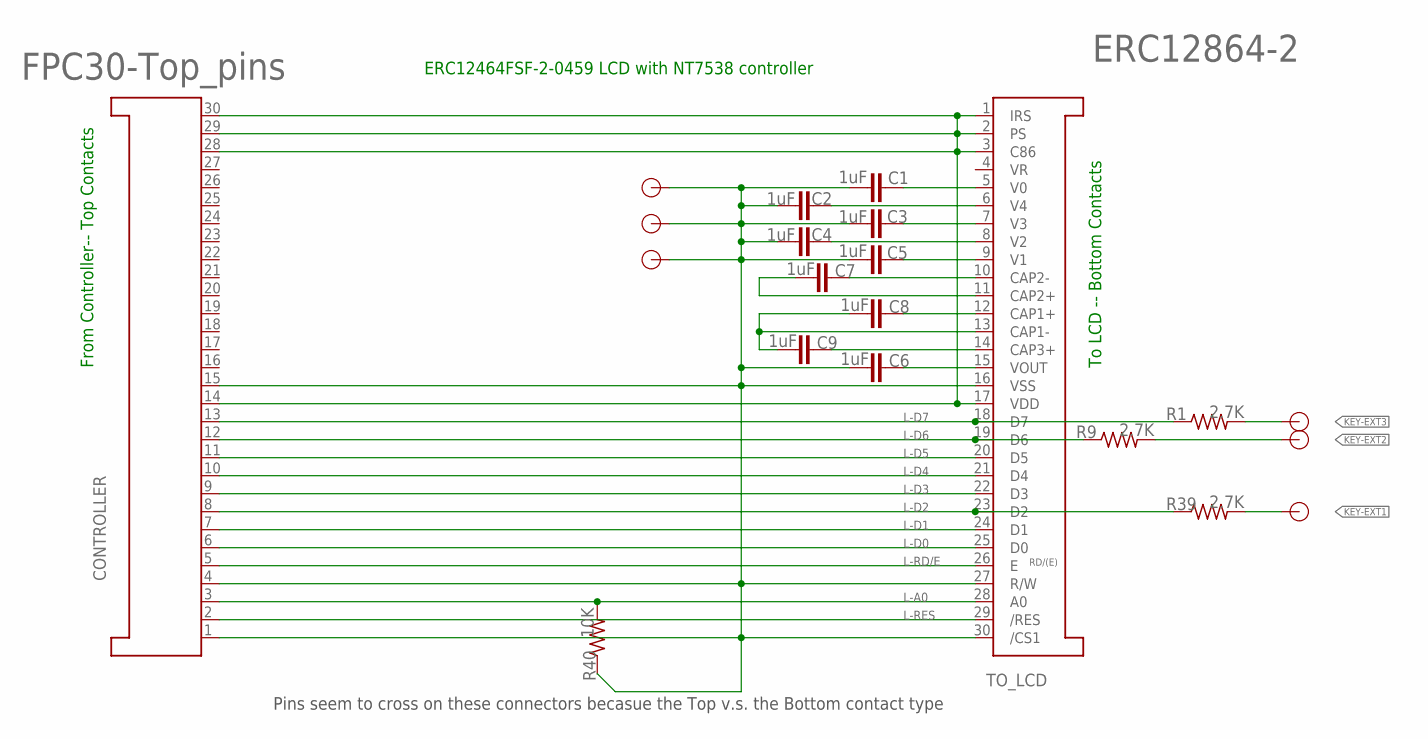
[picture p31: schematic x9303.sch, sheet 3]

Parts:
C1, C2, C3, C4, C5, C6, C7, C8, C9: 1uF; C0805
CONTROLLER: FPC30-Top_pins; FH12-30S-0.5SH; DIGIKEY 732-3517-ND
K1, K2, K3: TP-1; TP
K_EXT4, K_EXT5, K_EXT6: TP-1; TP
R1, R9, R39: 2.7K; R0603
R40: 10K; R0603
TO_LCD: ERC12864-2; FH12-30S-0.5SH; DIGIKEY 732-3518-ND

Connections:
KEY-EXT1: K1.P$1, R39.2
KEY-EXT2: K2.P$1, R9.2
KEY-EXT3: K3.P$1, R1.2
L-A0: CONTROLLER.3, R40.2, TO_LCD.28 (A0)
L-D0: CONTROLLER.6, TO_LCD.25 (D0)
L-D1: CONTROLLER.7, TO_LCD.24 (D1)
L-D2: CONTROLLER.8, R39.1, TO_LCD.23 (D2)
L-D3: CONTROLLER.9, TO_LCD.22 (D3)
L-D4: CONTROLLER.10, TO_LCD.21 (D4)
L-D5: CONTROLLER.11, TO_LCD.20 (D5)
L-D6: CONTROLLER.12, R9.1, TO_LCD.19 (D6)
L-D7: CONTROLLER.13, R1.1, TO_LCD.18 (D7)
L-RD/E: CONTROLLER.5, TO_LCD.26 (E)
L-RES: CONTROLLER.2, TO_LCD.29 (/RES)
L_GND: C1.2, C2.2, C3.2, C4.2, C5.2, C6.2, CONTROLLER.1, CONTROLLER.4, CONTROLLER.15, K_EXT4.P$1, K_EXT5.P$1, K_EXT6.P$1, R40.1, TO_LCD.16 (VSS), TO_LCD.27 (R/W), TO_LCD.30 (/CS1)
L_VDD: CONTROLLER.14, CONTROLLER.28, CONTROLLER.29, CONTROLLER.30, TO_LCD.1 (IRS), TO_LCD.2 (PS), TO_LCD.3 (C86), TO_LCD.17 (VDD)
unnamed: C1.1, TO_LCD.5 (V0)
unnamed: C2.1, TO_LCD.6 (V4)
unnamed: C3.1, TO_LCD.7 (V3)
unnamed: C4.1, TO_LCD.8 (V2)
unnamed: C5.1, TO_LCD.9 (V1)
unnamed: C7.1, TO_LCD.10 (CAP2-)
unnamed: C7.2, TO_LCD.11 (CAP2+)
unnamed: C8.2, C9.2, TO_LCD.13 (CAP1-)
unnamed: C8.1, TO_LCD.12 (CAP1+)
unnamed: C9.1, TO_LCD.14 (CAP3+)
unnamed: C6.1, TO_LCD.15 (VOUT)

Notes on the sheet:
RD/(E)
From Controller-- Top Contacts
To LCD -- Bottom Contacts
Pins seem to cross on these connectors becasue the Top v.s. the Bottom contact type
ERC12464FSF-2-0459 LCD with NT7538 controller

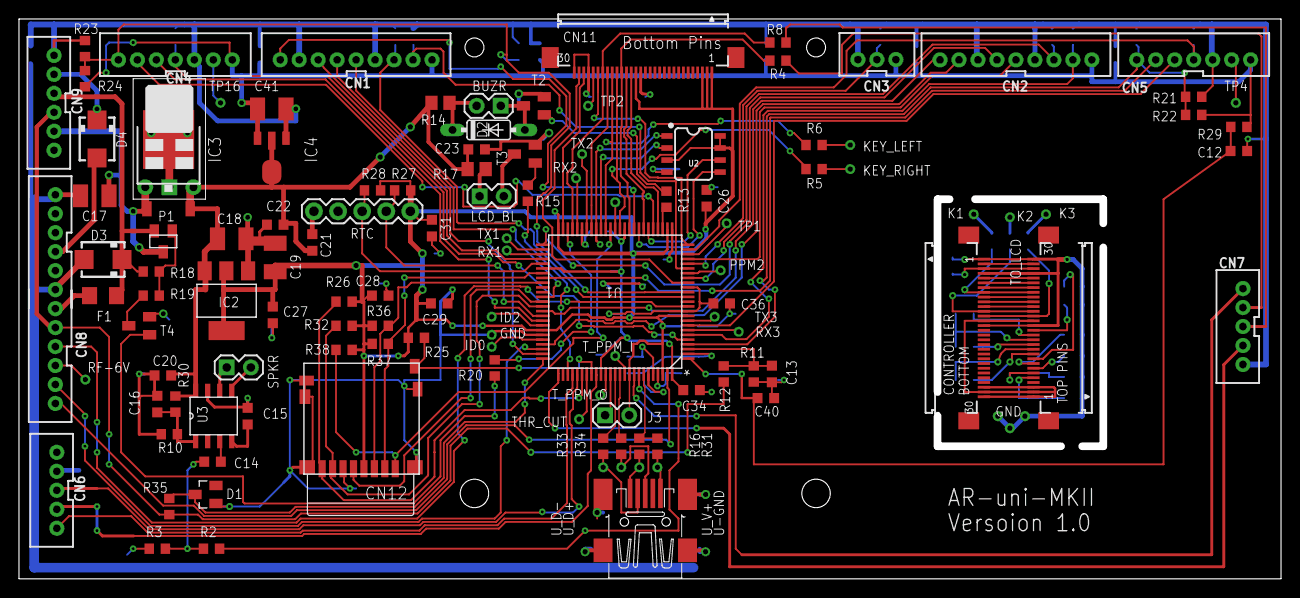
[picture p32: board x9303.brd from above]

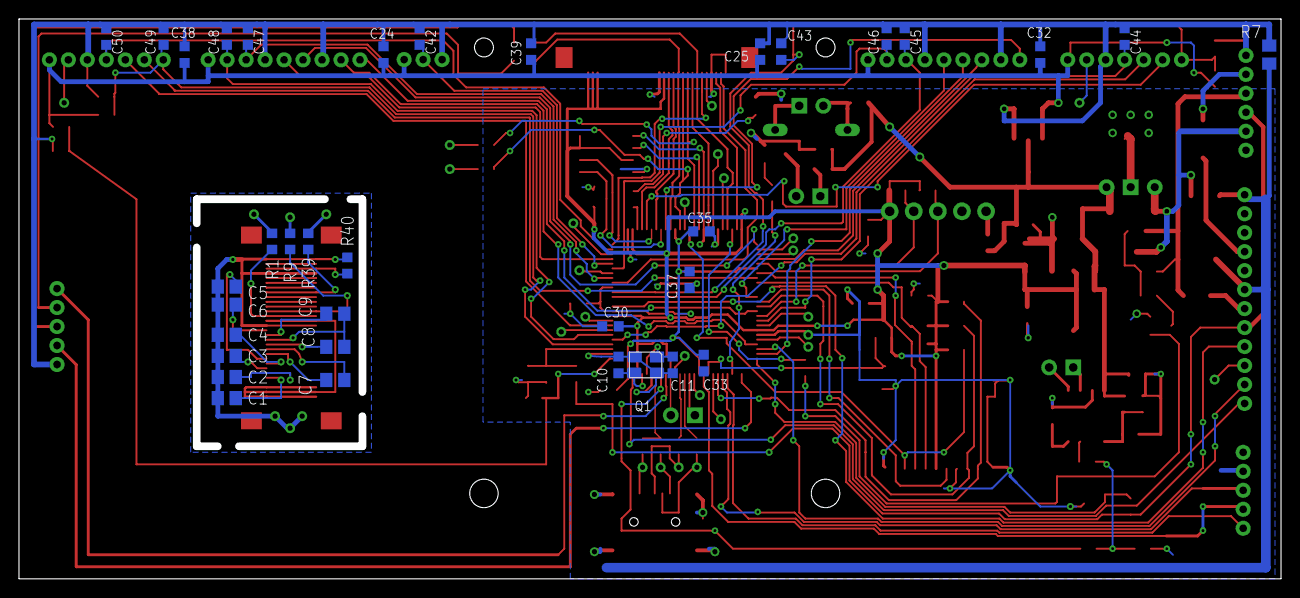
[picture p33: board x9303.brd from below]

Board: 2 copper layers, 133.0 x 59.0 mm, 158 parts (35 on the bottom side), 144 nets.

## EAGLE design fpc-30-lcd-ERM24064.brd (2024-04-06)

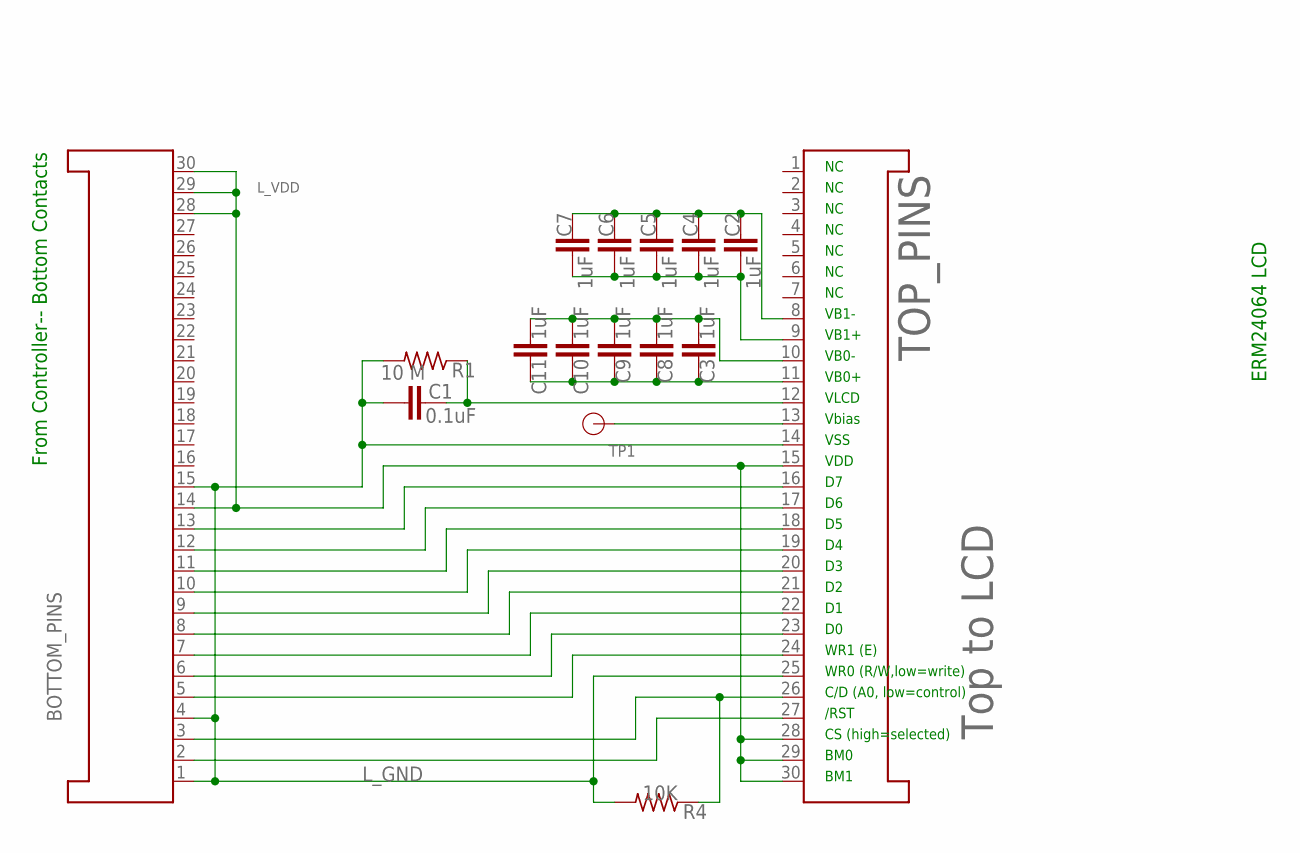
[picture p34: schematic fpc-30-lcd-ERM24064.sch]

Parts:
BOTTOM_PINS: FPC30-bottom_pins; FH12-30S-0.5SH; DIGIKEY 732-3517-ND
C1: 0.1uF; C0603K
C2, C3, C4, C5, C6, C7, C8, C9, C10, C11: 1uF; C0603K
R1: 10 M; R0603
R4: 10K; R0603
TOP_PINS: Top to LCD; FH12-30S-0.5SH
TP1: TP-1; TP

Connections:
L-A0: BOTTOM_PINS.3, R4.1, TOP_PINS.26
L-D0: BOTTOM_PINS.6, TOP_PINS.23
L-D1: BOTTOM_PINS.7, TOP_PINS.22
L-D3: BOTTOM_PINS.9, TOP_PINS.20
L-D4: BOTTOM_PINS.10, TOP_PINS.19
L-D5: BOTTOM_PINS.11, TOP_PINS.18
L-D6: BOTTOM_PINS.12, TOP_PINS.17
L-RD/E: BOTTOM_PINS.5, TOP_PINS.24
L-RES: BOTTOM_PINS.2, TOP_PINS.27
L_D7: BOTTOM_PINS.13, TOP_PINS.16
L_GND: BOTTOM_PINS.1, BOTTOM_PINS.4, BOTTOM_PINS.15, C1.2, R1.2, R4.2, TOP_PINS.14, TOP_PINS.25
L_VDD: BOTTOM_PINS.14, BOTTOM_PINS.28, BOTTOM_PINS.29, BOTTOM_PINS.30, TOP_PINS.15, TOP_PINS.28, TOP_PINS.29, TOP_PINS.30
unnamed: C1.1, R1.1, TOP_PINS.12
unnamed: TOP_PINS.13, TP1.P$1
unnamed: C2.1, C4.1, C5.1, C6.1, C7.1, TOP_PINS.8
unnamed: C3.2, C8.2, C9.2, C10.2, C11.2, TOP_PINS.10
unnamed: C2.2, C4.2, C5.2, C6.2, C7.2, TOP_PINS.9
unnamed: C3.1, C8.1, C9.1, C10.1, C11.1, TOP_PINS.11
unnamed: BOTTOM_PINS.8, TOP_PINS.21

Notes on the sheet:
From Controller-- Bottom Contacts
ERM24064 LCD
VB1-
VB1+
VB0-
VB0+
VLCD
Vbias
VSS
VDD
WR1 (E)
WR0 (R/W,low=write)
C/D (A0, low=control)
/RST
CS (high=selected)
BM0
BM1

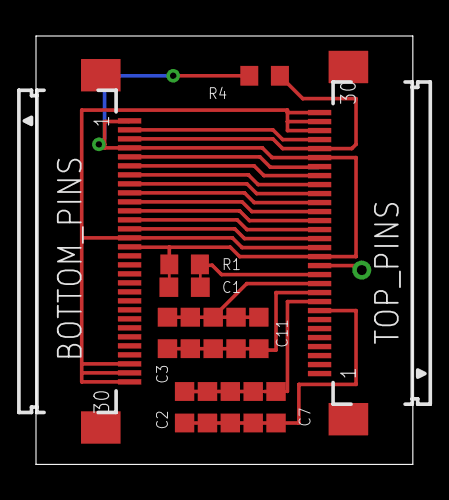
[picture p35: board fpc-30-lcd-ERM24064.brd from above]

Board: 2 copper layers, 20.9 x 23.8 mm, 16 parts (0 on the bottom side), 19 nets.

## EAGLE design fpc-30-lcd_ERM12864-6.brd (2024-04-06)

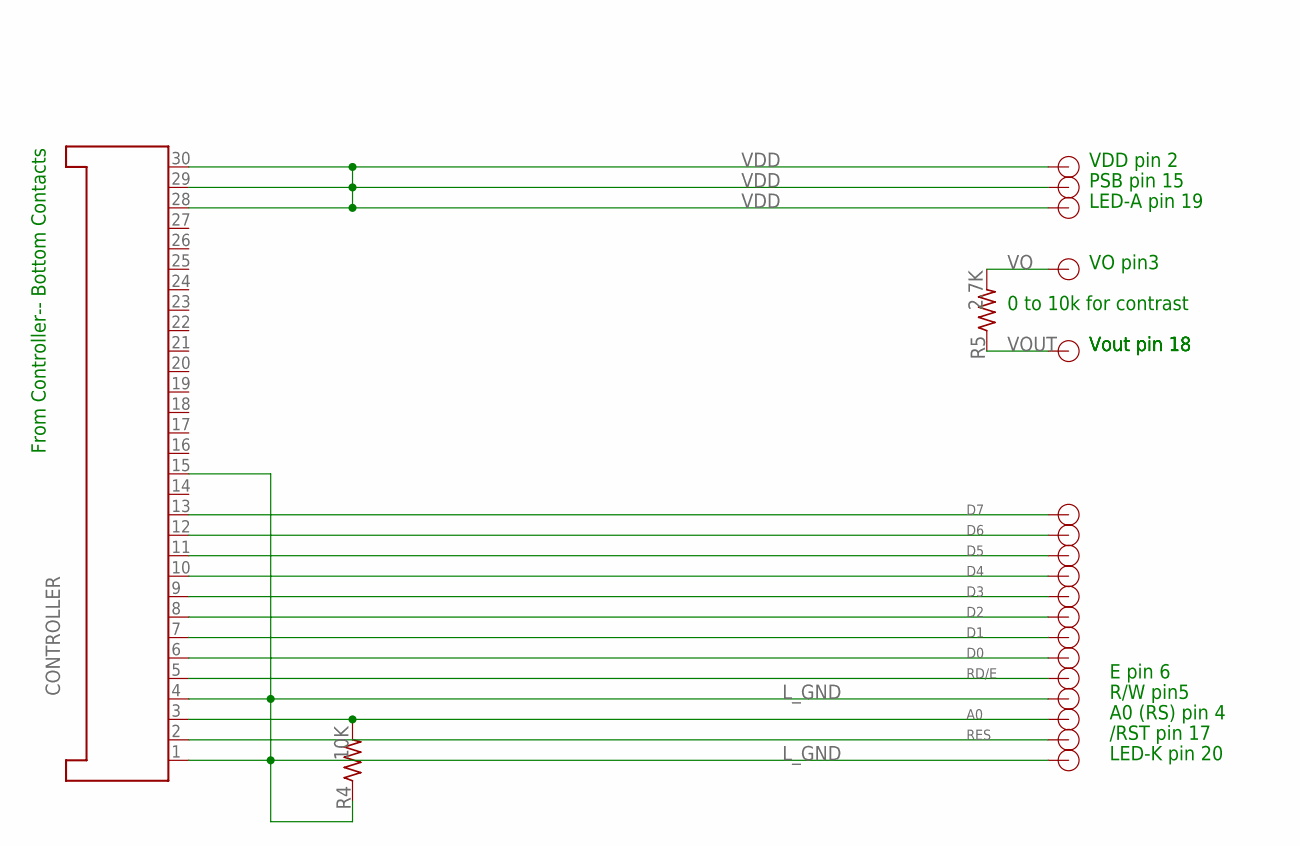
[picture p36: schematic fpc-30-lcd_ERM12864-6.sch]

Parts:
/RST: TP-1; TP
A0/RS: TP-1; TP
CONTROLLER: FPC30-Top_pins; FH12-30S-0.5SH; DIGIKEY 732-3517-ND
D0, D7: D7; TP
D1, D2, D3, D4, D5, D6: TP-1; TP
LED_A: TP-1; TP
LED_K: TP-1; TP
PSB: TP-1; TP
R4: 10K; R0603
R5: 2.7K; R0603
R/W: TP-1; TP
RD/E: TP-1; TP
VDD: TP-1; TP
VO: D7; TP
VOUT: D7; TP

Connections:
A0: A0/RS.P$1, CONTROLLER.3, R4.2
D0: CONTROLLER.6, D0.P$1
D1: CONTROLLER.7, D1.P$1
D2: CONTROLLER.8, D2.P$1
D3: CONTROLLER.9, D3.P$1
D4: CONTROLLER.10, D4.P$1
D5: CONTROLLER.11, D5.P$1
D6: CONTROLLER.12, D6.P$1
D7: CONTROLLER.13, D7.P$1
L_GND: CONTROLLER.1, CONTROLLER.4, CONTROLLER.15, LED_K.P$1, R4.1, R/W.P$1
RD/E: CONTROLLER.5, RD/E.P$1
RES: /RST.P$1, CONTROLLER.2
VDD: CONTROLLER.28, CONTROLLER.29, CONTROLLER.30, LED_A.P$1, PSB.P$1, VDD.P$1
VO: R5.2, VO.P$1
VOUT: R5.1, VOUT.P$1

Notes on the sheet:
From Controller-- Bottom Contacts
VDD pin 2
PSB pin 15
A0 (RS) pin 4
R/W pin5
/RST pin 17
E pin 6
LED-K pin 20
LED-A pin 19
VO pin3
Vout pin 18
0 to 10k for contrast

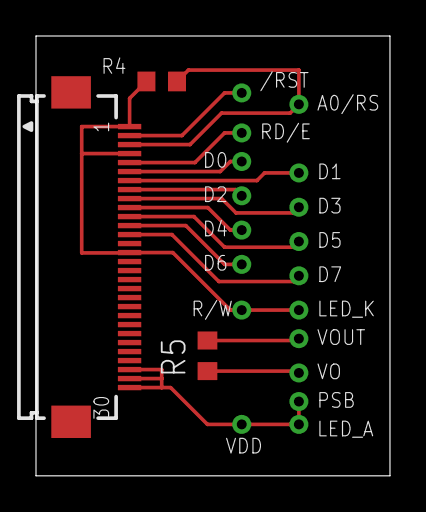
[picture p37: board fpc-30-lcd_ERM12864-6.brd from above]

Board: 2 copper layers, 19.7 x 24.4 mm, 21 parts (0 on the bottom side), 15 nets.

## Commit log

2021-04-22 Initial check in
    [fpc-30-lcd-adapter.brd, fpc-30-lcd-adapter.sch, x9303.brd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]
2021-04-22 Added prior docs and current tools
    [ARUni_Wiring_v14.dwg]
2021-04-22 added labels for connector pins on layout layer 150
    [x9303.brd]
2024-04-06 added pictures and docs added firmware binary added old JR9303 wiring and pin-out doc added lcd display adapter patch boards for different displays
    [ARuniMKII_DIGIKEY_BOM.csv, fpc-30-lcd-ERM24064.brd, fpc-30-lcd-ERM24064.sch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]
2024-06-05 added binaries supporting new LCD modules added pdf on how to bootstrap with SAMBA added schematic and layout pictures in PNG format
